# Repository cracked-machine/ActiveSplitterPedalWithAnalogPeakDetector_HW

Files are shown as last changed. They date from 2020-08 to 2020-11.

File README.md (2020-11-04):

## Active 4-way splitter pedal with analog peak detector

Required Kicad Hardware library: https://github.com/cracked-machine/KicadLibrary

- Analog 1->4 splitter circuit with buffered input and output gain controls.
- Analog LED peak detector per output channel.
- Fits in a Hammond 1590BB enclosure (120mm x 95mm).

### System Overview



### Schematic

##### Top Level



##### Power Supply block



##### Buffer/Attenuator block



##### Peak Detector block



## 3D Renderings

__PCB 3D Render (top view)__

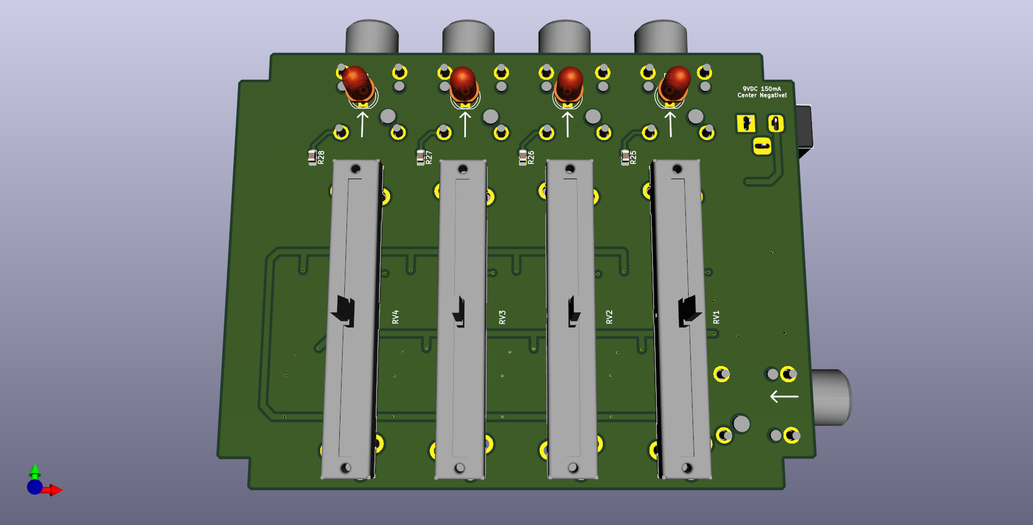
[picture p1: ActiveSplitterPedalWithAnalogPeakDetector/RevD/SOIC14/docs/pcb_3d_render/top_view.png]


__PCB 3D Render (bottom view)__

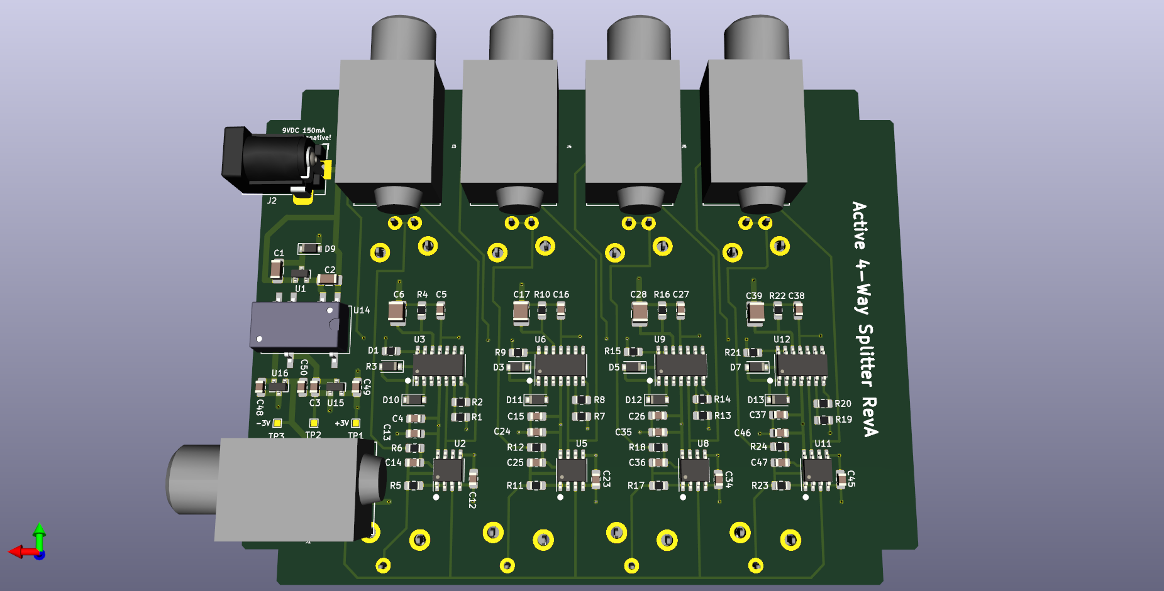
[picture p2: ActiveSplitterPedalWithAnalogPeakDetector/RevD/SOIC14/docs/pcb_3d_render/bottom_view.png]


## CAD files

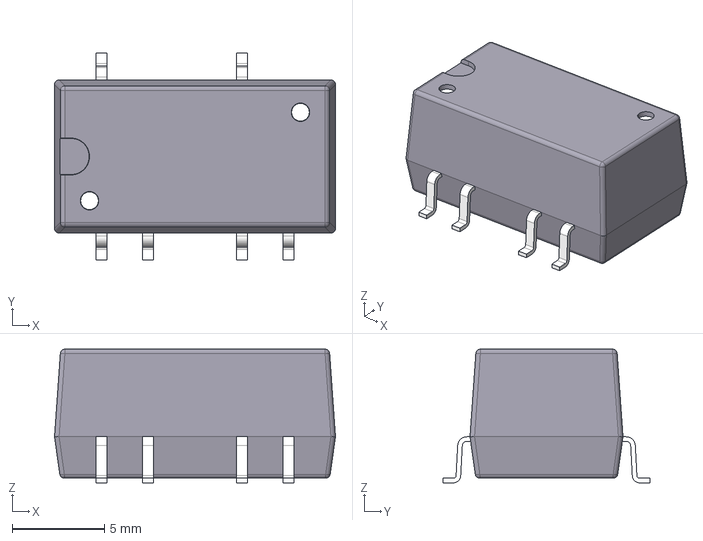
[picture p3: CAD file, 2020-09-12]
ActiveSplitterPedalWithAnalogPeakDetector/RevD/SOIC14/3D/ISA.STEP
15.2 x 11.2 x 7.25 mm

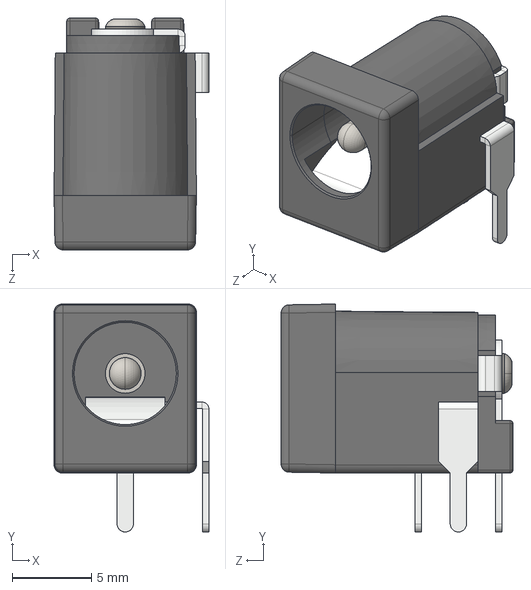
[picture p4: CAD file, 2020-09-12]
ActiveSplitterPedalWithAnalogPeakDetector/RevD/SOIC14/3D/DC Power Jack 5.5mm x 2.1mm.STEP
9.77 x 14.4 x 14.6 mm

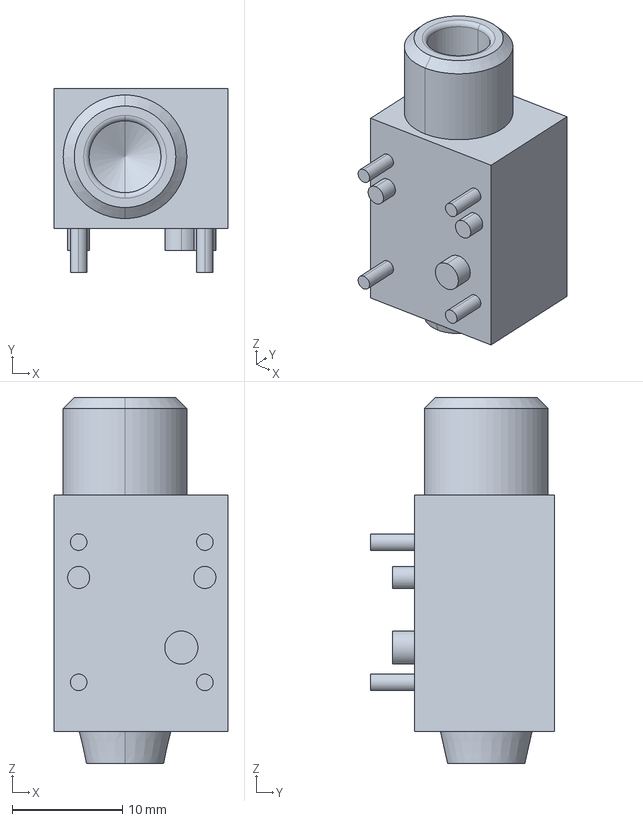
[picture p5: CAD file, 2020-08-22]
ActiveSplitterPedalWithAnalogPeakDetector/RevD/SOIC14/3D/3D+File+NRJ4HF.stp
15.8 x 16.7 x 33.1 mm

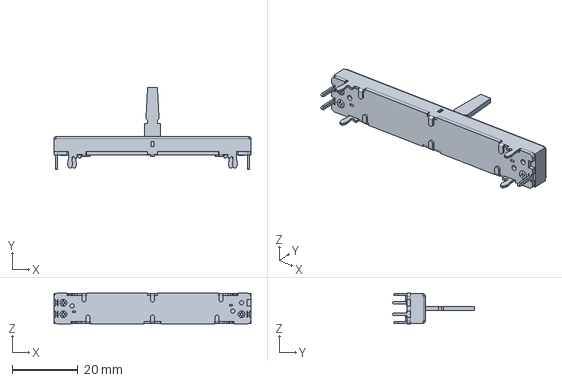
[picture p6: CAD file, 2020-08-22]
ActiveSplitterPedalWithAnalogPeakDetector/RevD/SOIC14/3D/pta4543-2015dpb103.stp
60.0 x 25.0 x 9.30 mm

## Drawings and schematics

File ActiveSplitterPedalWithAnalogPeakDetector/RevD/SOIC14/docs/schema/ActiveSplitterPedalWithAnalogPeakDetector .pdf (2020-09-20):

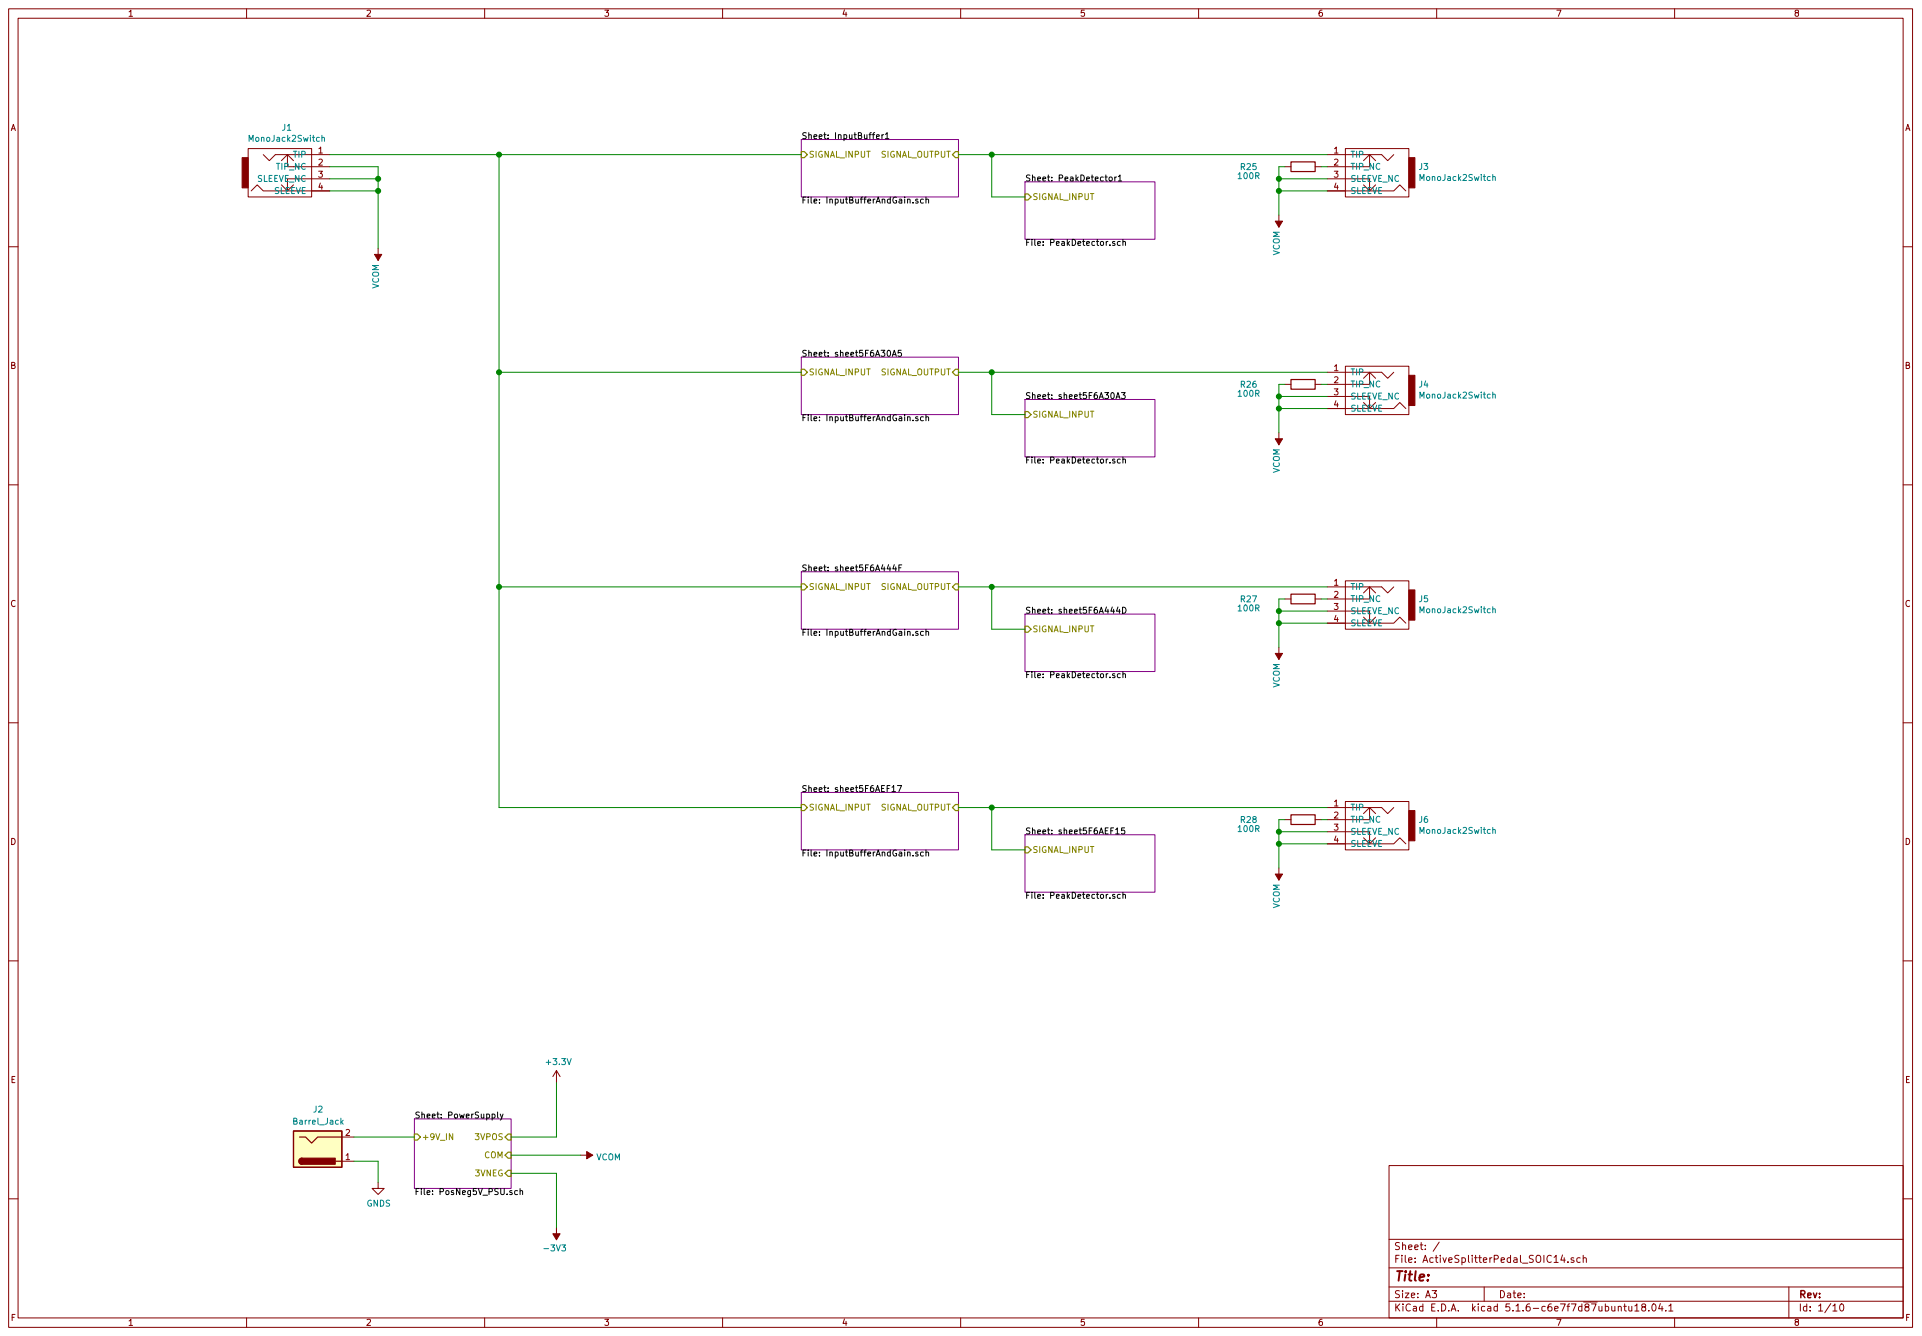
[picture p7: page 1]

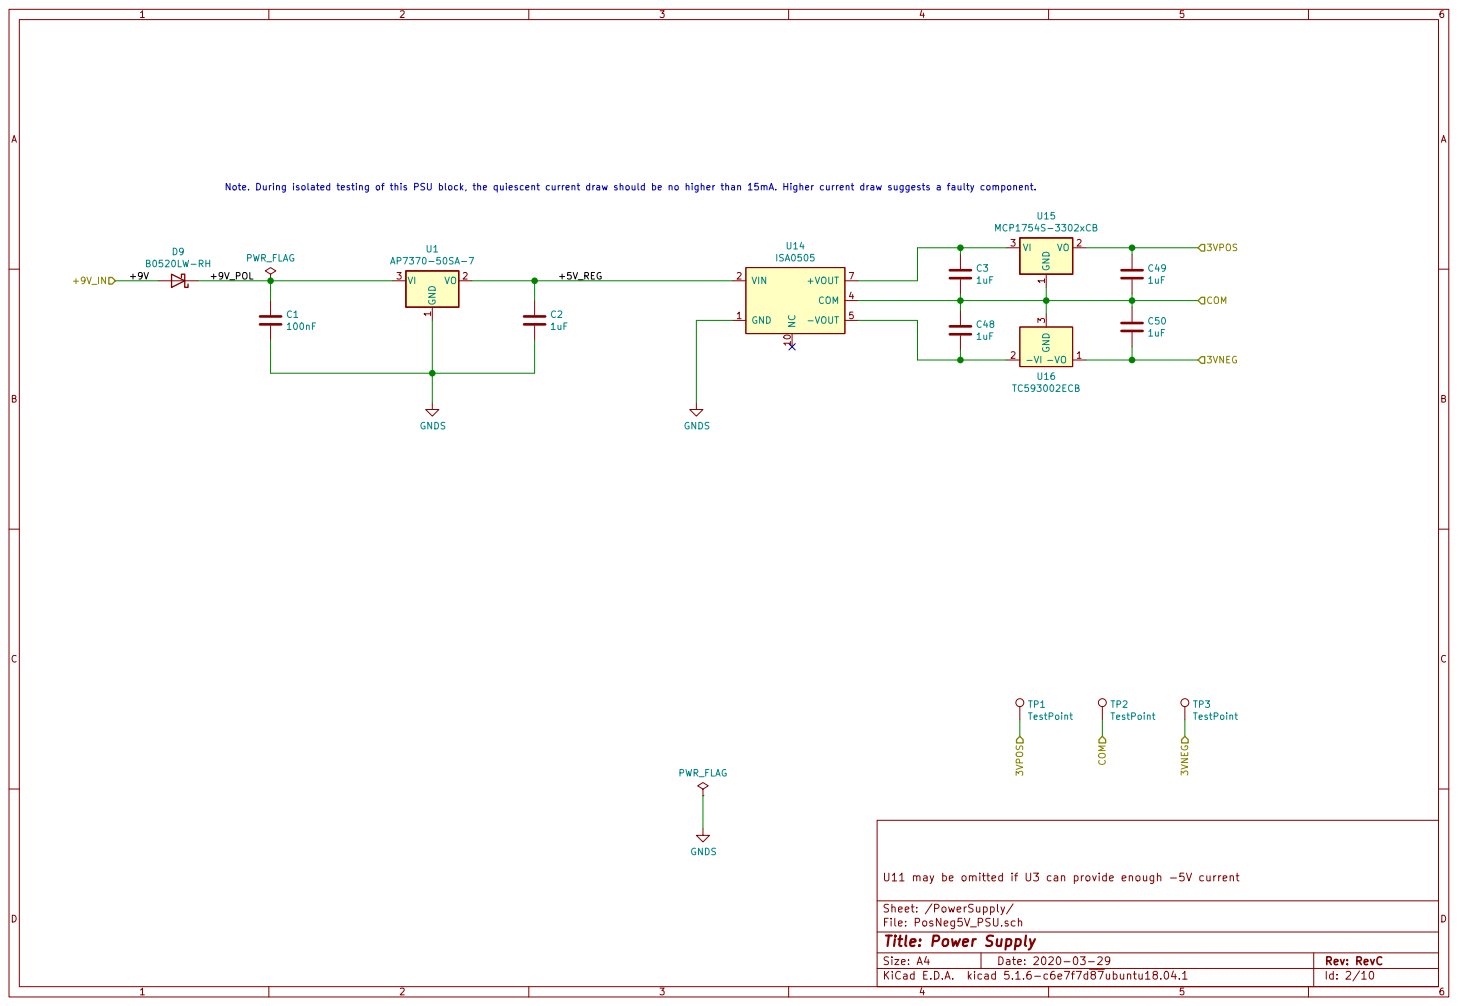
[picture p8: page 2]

U11 may be omitted if U3 can provide enough -5V current GND
ISA0505 GNDS

Note. During isolated testing of this PSU block, the quiescent current draw should be no higher than 15mA. Higher current draw suggests a faulty component.

3 U16 TC593002ECB GNDS GND 1 NC 10 VIN 2 COM 4

Sheet: /PowerSupply/
File: PosNeg5V_PSU.sch
Id: 2/10 Title: Power Supply

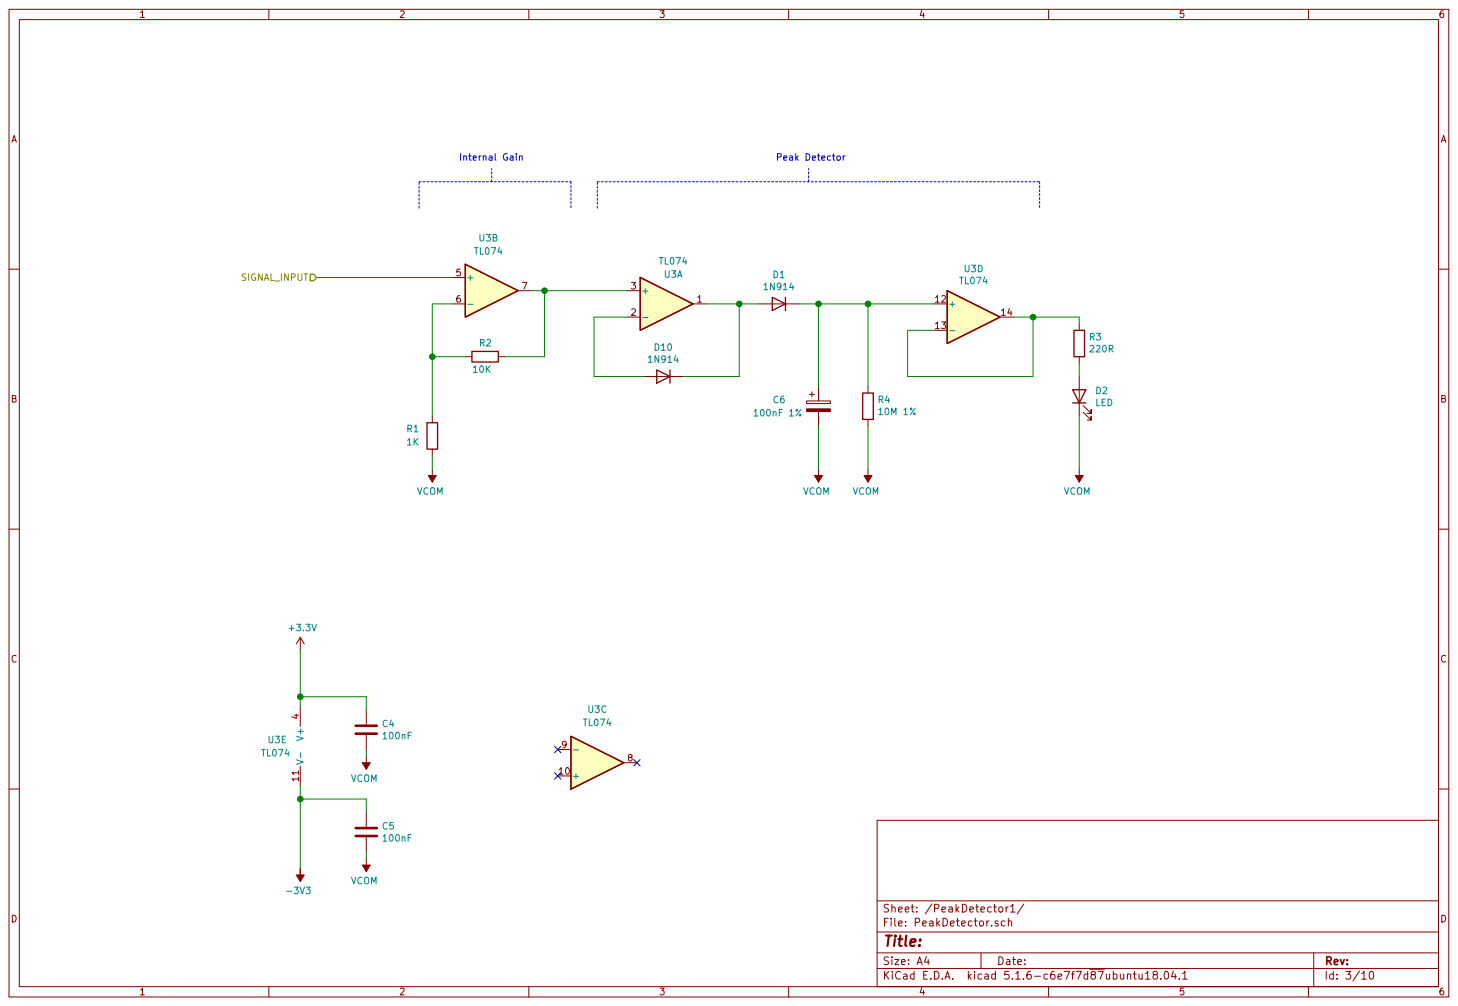
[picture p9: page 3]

Id: 3/10 Title: File: PeakDetector.sch Sheet: /PeakDetector1/ VCOM

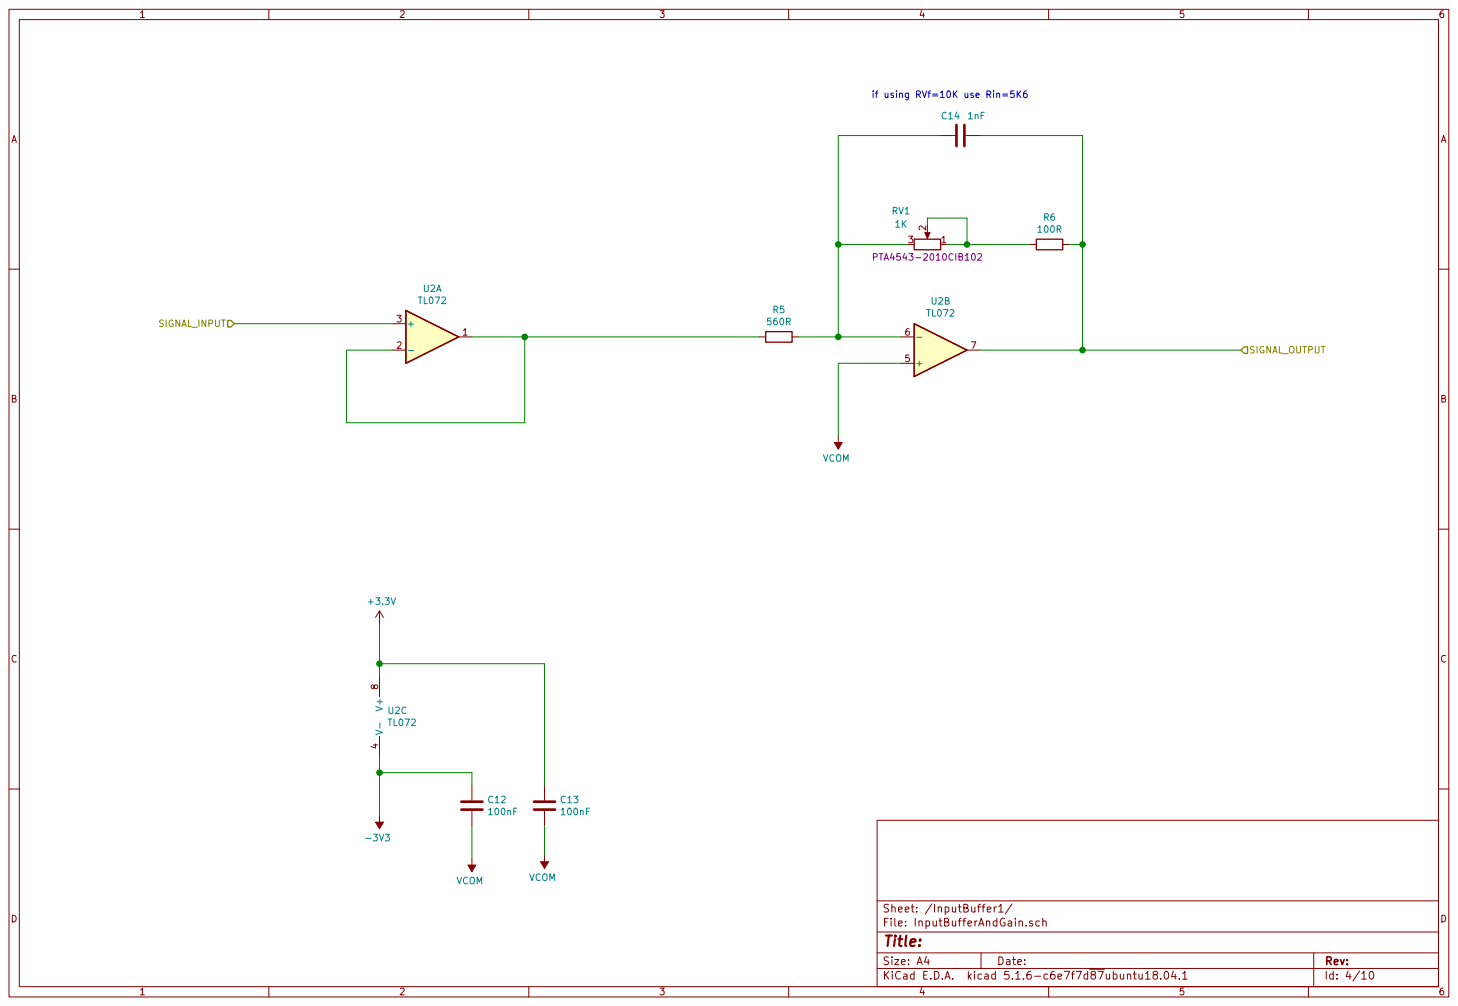
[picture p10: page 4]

if using RVf=10K use Rin=5K6

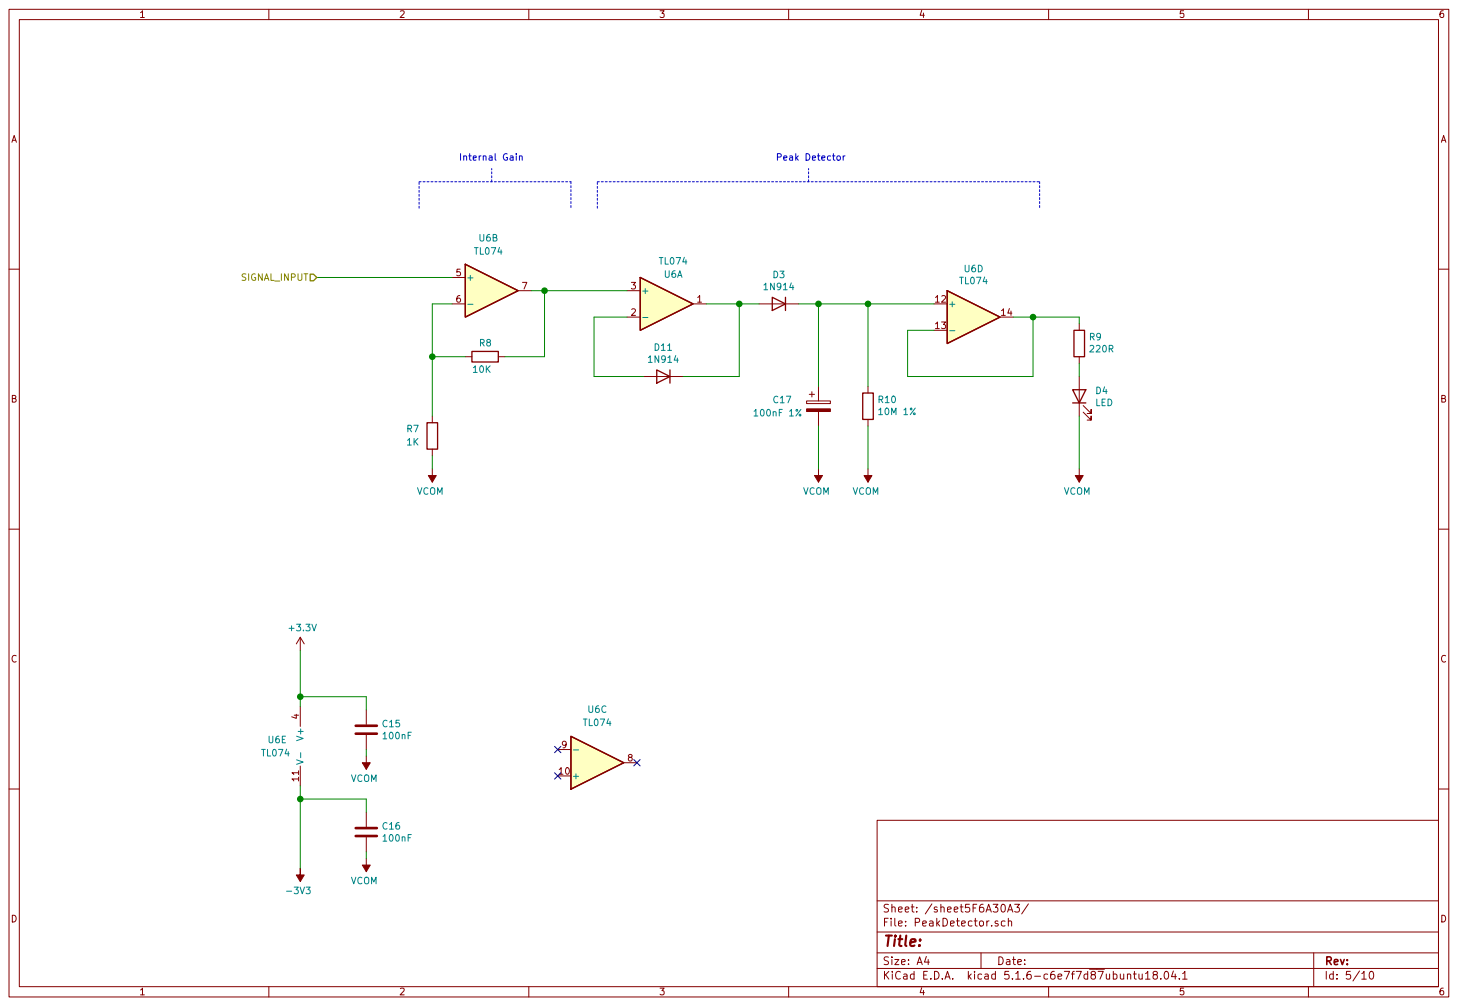
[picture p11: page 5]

Id: 5/10 Title: File: PeakDetector.sch Sheet: /sheet5F6A30A3/ VCOM

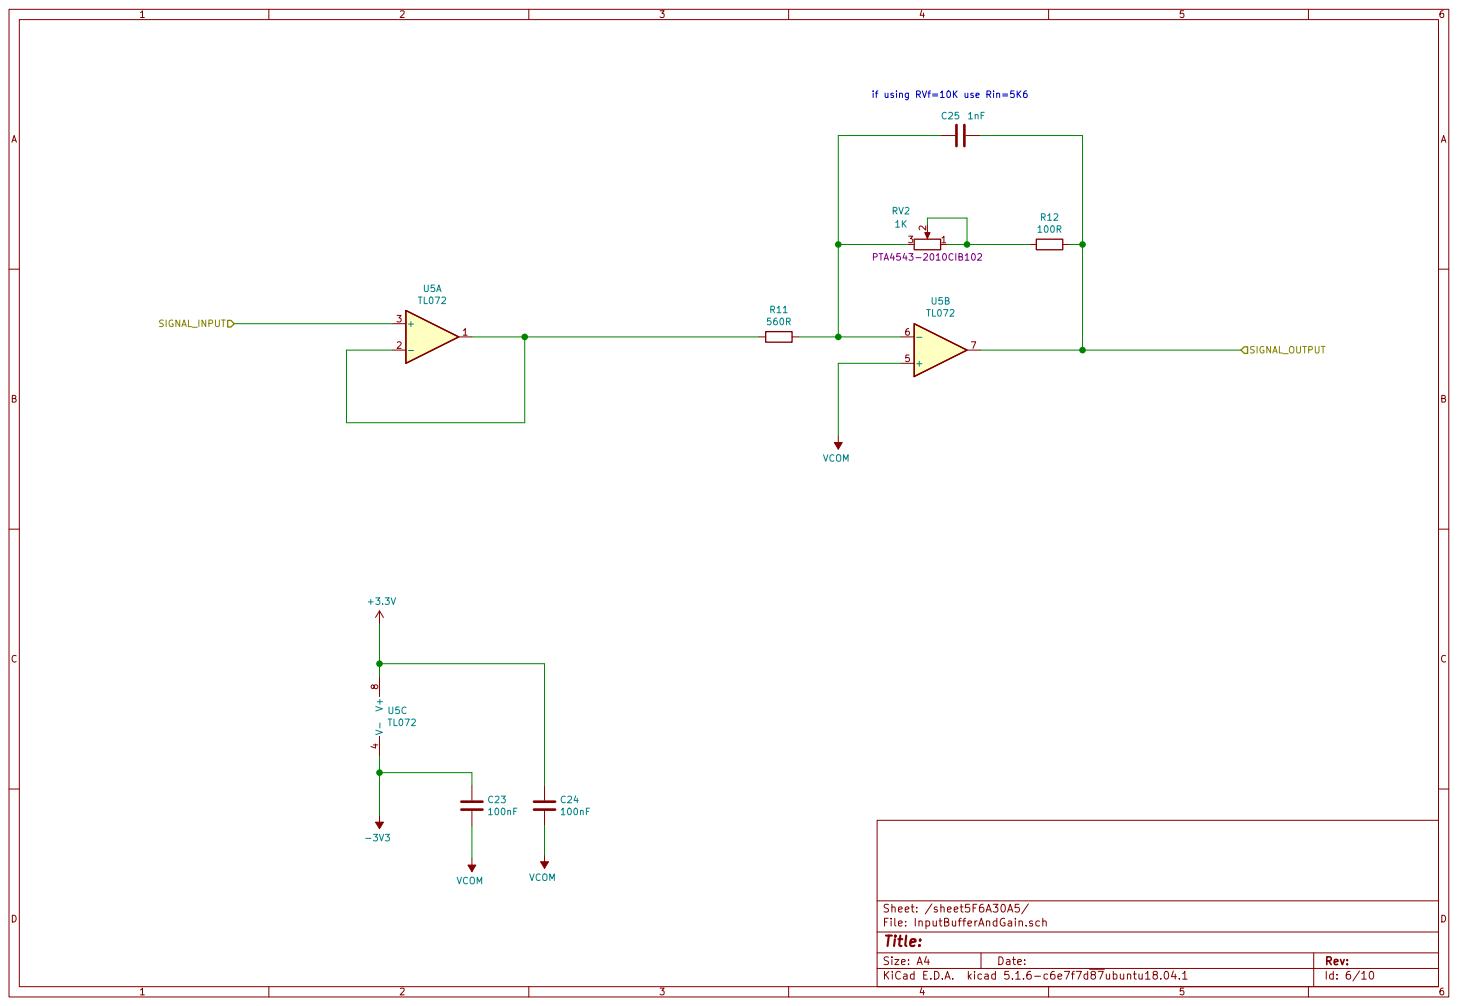
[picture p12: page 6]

if using RVf=10K use Rin=5K6

File: InputBufferAndGain.sch Sheet: /sheet5F6A30A5/
Id: 6/10 Title:

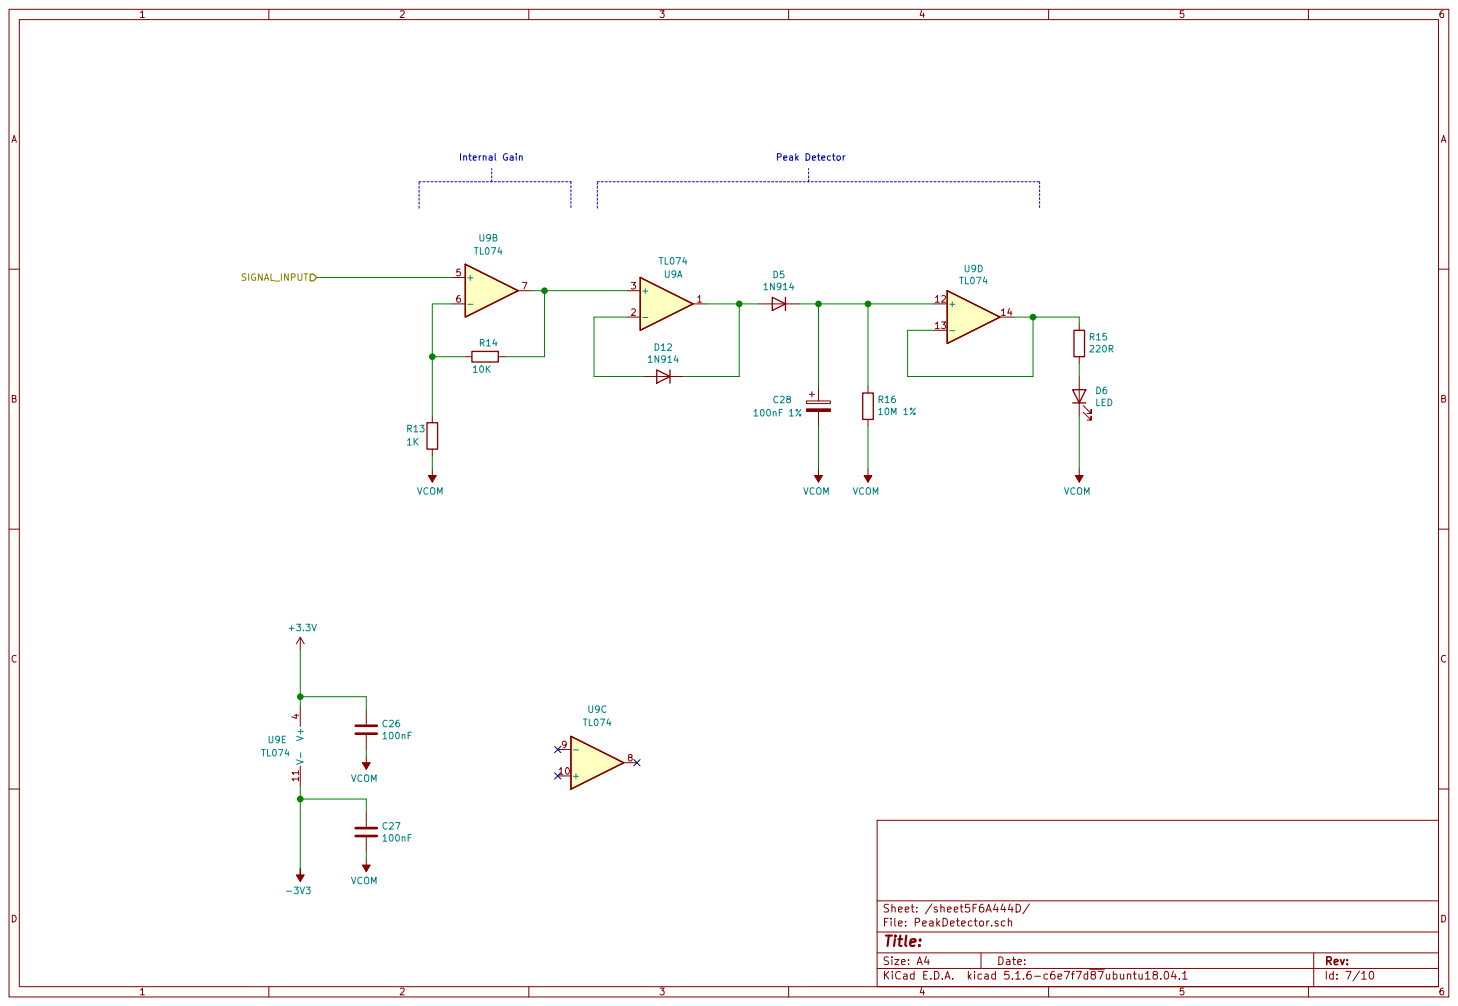
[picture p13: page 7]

Id: 7/10 Title: File: PeakDetector.sch Sheet: /sheet5F6A444D/ VCOM

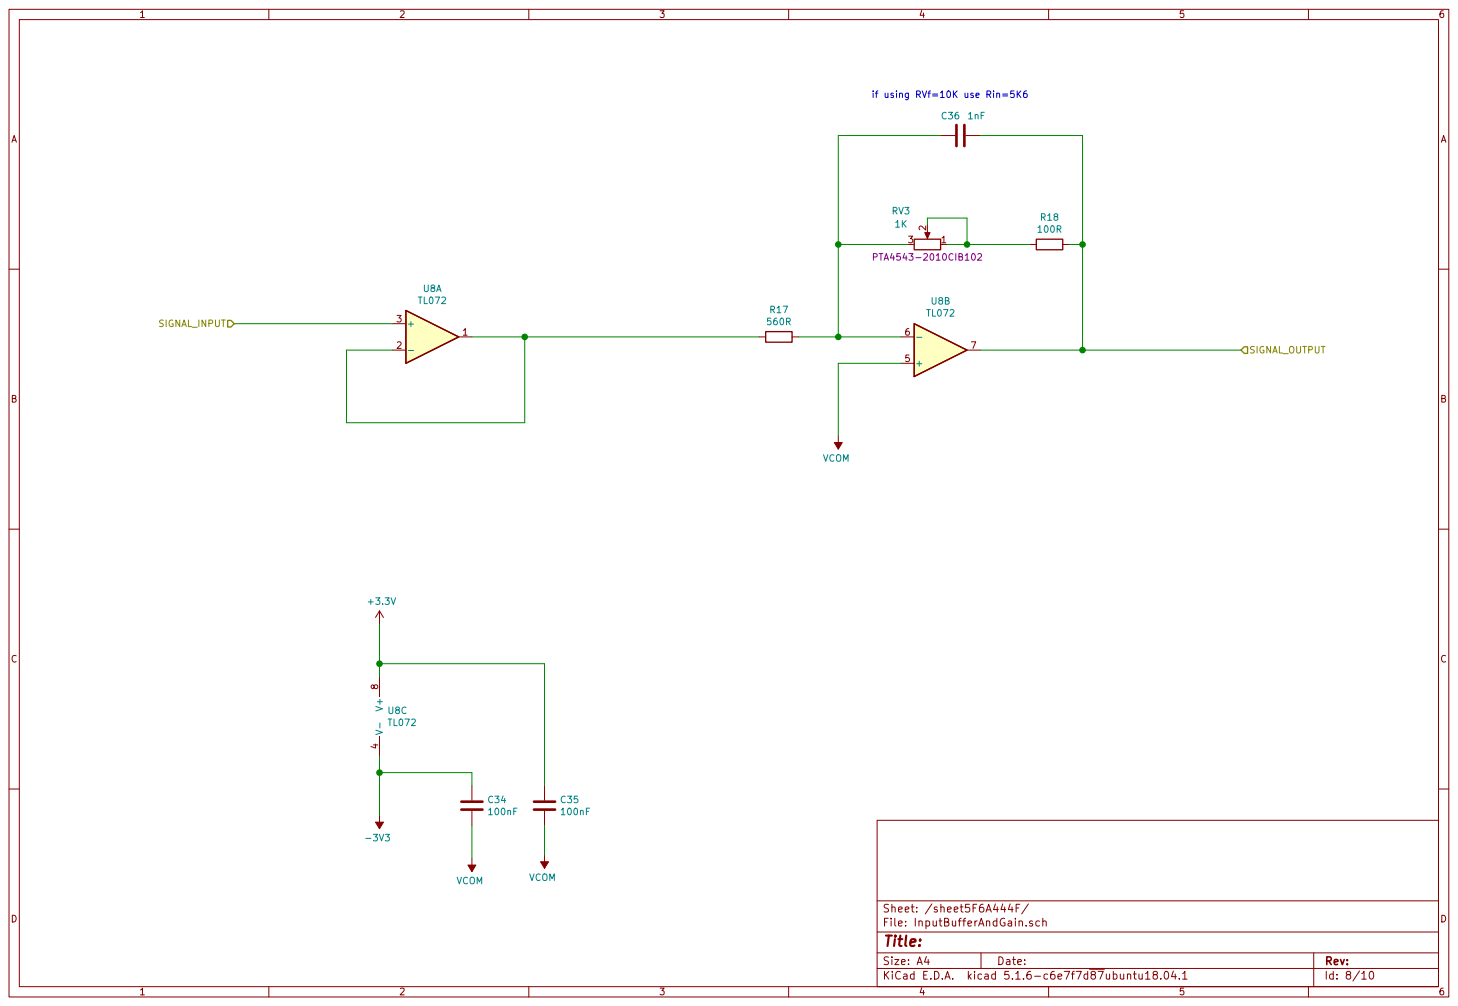
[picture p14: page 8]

if using RVf=10K use Rin=5K6

File: InputBufferAndGain.sch Sheet: /sheet5F6A444F/
Id: 8/10 Title:

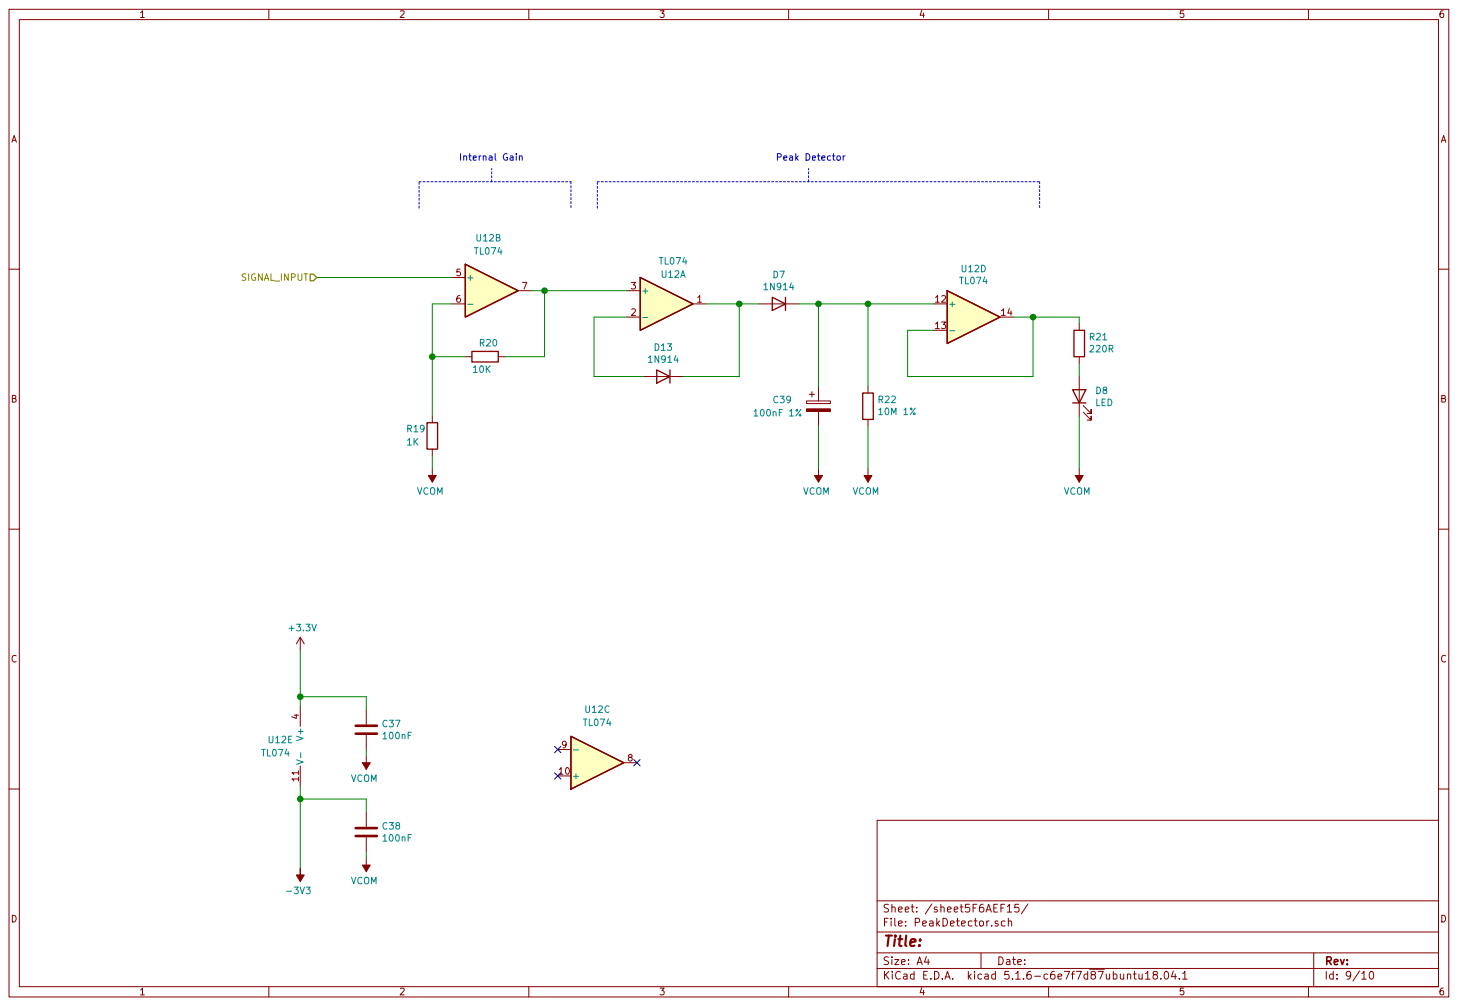
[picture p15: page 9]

Id: 9/10 Title: File: PeakDetector.sch Sheet: /sheet5F6AEF15/ VCOM

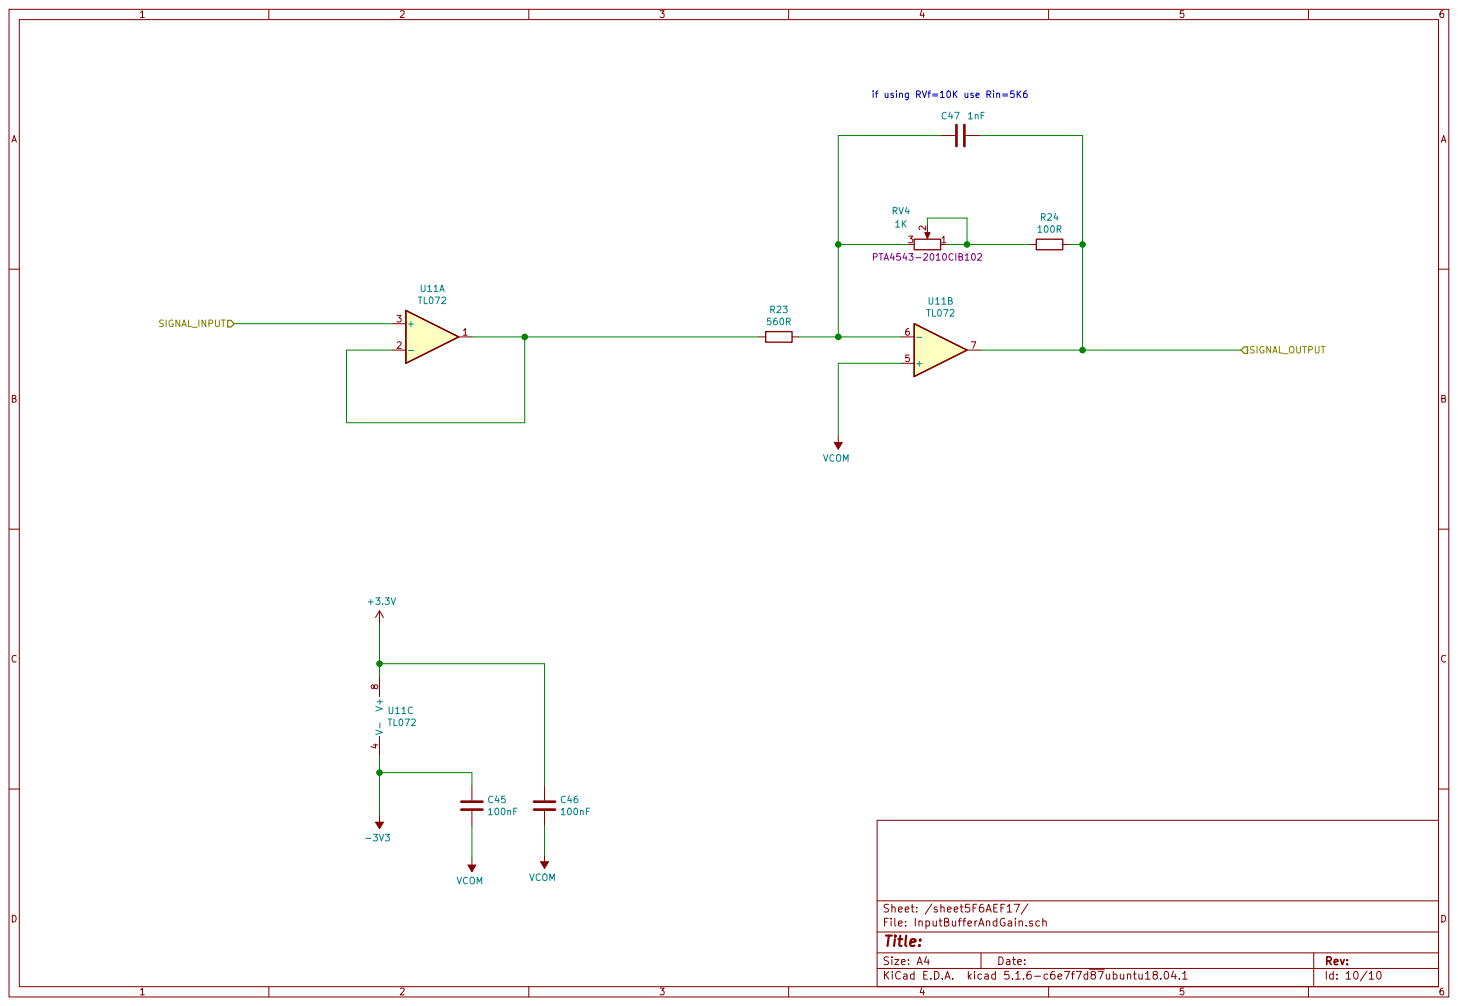
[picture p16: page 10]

if using RVf=10K use Rin=5K6

File: InputBufferAndGain.sch Sheet: /sheet5F6AEF17/
Id: 10/10 Title:

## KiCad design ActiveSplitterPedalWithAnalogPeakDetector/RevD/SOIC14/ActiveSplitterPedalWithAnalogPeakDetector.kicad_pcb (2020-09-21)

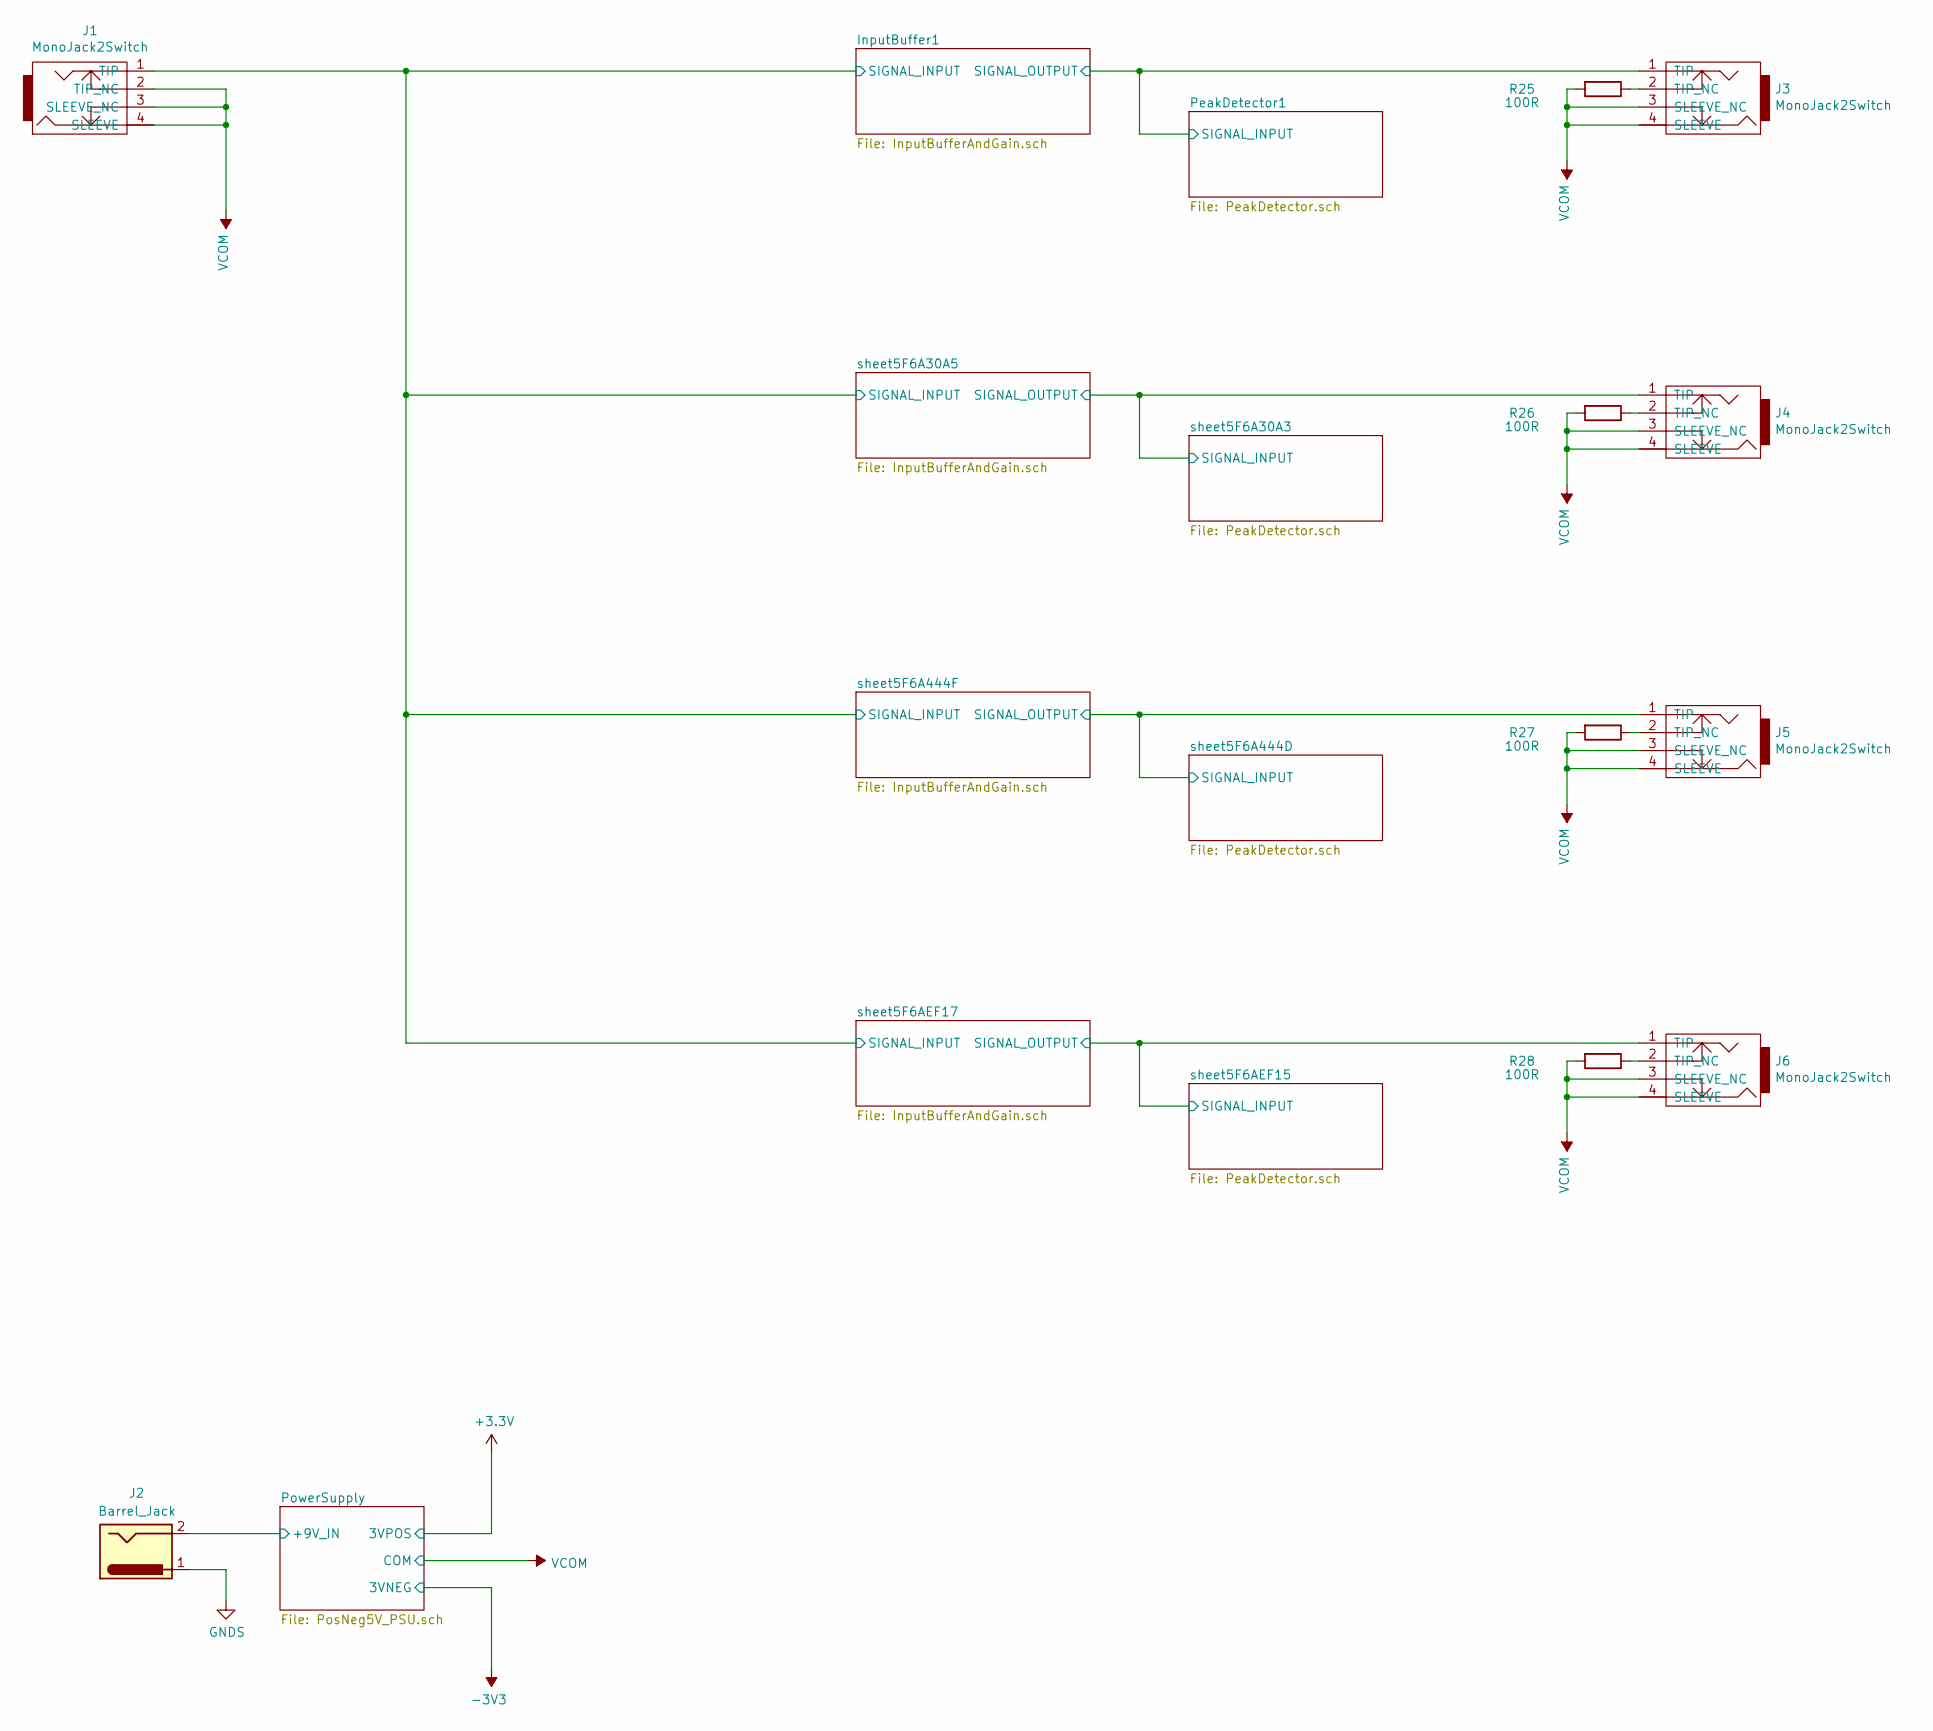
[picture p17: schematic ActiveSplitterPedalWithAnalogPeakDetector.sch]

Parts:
J1, J3, J4, J5, J6: MonoJack2Switch; NRJxHx
J2: Barrel_Jack; BarrelJack_Horizontal
R25, R26, R27, R28: 100R; C_0805_2012Metric_Pad1.15x1.40mm_HandSolder

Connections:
/InputBuffer1/SIGNAL_INPUT: J1.1 (TIP); also elsewhere on the board
/PeakDetector1/SIGNAL_INPUT: J3.1 (TIP); also elsewhere on the board
/PowerSupply/+9V_IN: J2.2; also elsewhere on the board
/sheet5F6A30A3/SIGNAL_INPUT: J4.1 (TIP); also elsewhere on the board
/sheet5F6A444D/SIGNAL_INPUT: J5.1 (TIP); also elsewhere on the board
/sheet5F6AEF15/SIGNAL_INPUT: J6.1 (TIP); also elsewhere on the board
GNDS: J2.1; also elsewhere on the board
unnamed: J3.2 (TIP_NC), R25.1
unnamed: J4.2 (TIP_NC), R26.1
unnamed: J5.2 (TIP_NC), R27.1
unnamed: J6.2 (TIP_NC), R28.1
VCOM: J1.2 (TIP_NC), J1.3 (SLEEVE_NC), J1.4 (SLEEVE), J3.3 (SLEEVE_NC), J3.4 (SLEEVE), J4.3 (SLEEVE_NC), J4.4 (SLEEVE), J5.3 (SLEEVE_NC), J5.4 (SLEEVE), J6.3 (SLEEVE_NC), J6.4 (SLEEVE), R25.2, R26.2, R27.2, R28.2; also elsewhere on the board

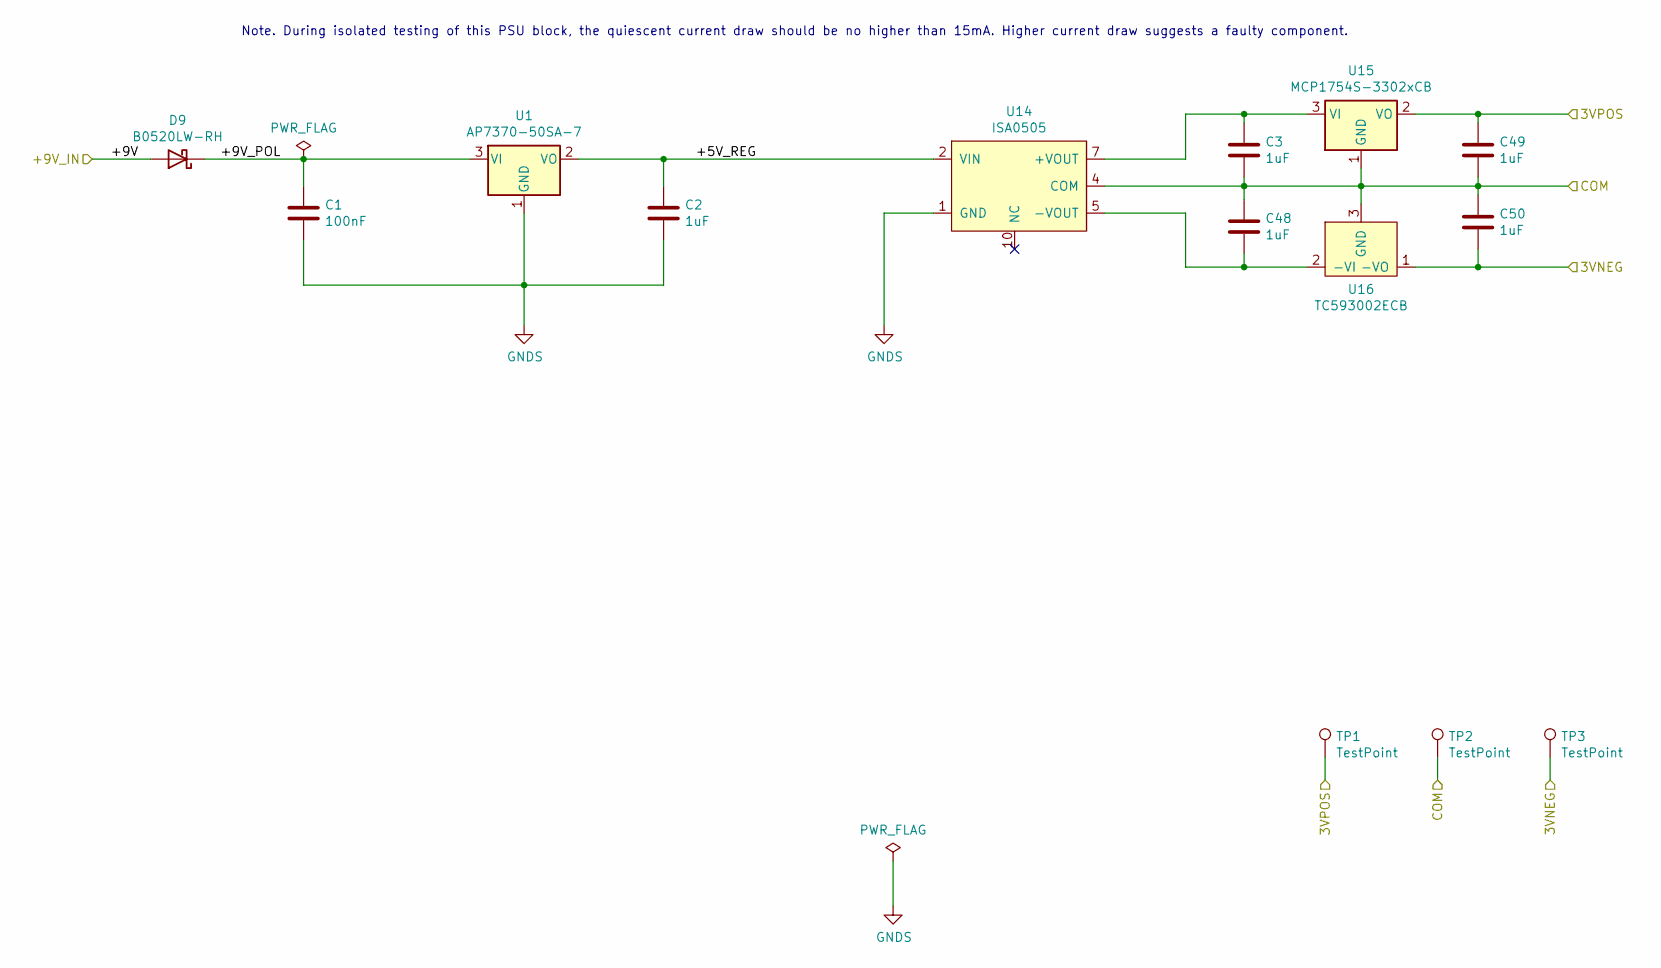
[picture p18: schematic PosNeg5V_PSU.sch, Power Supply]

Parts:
C1: 100nF; C_1206_3216Metric_Pad1.42x1.75mm_HandSolder
C2: 1uF; C_1206_3216Metric_Pad1.42x1.75mm_HandSolder
C3, C48, C49, C50: 1uF; C_0805_2012Metric_Pad1.15x1.40mm_HandSolder
D9: B0520LW-RH; D_SOD-123F
TP1, TP2, TP3: TestPoint; TestPoint_Pad_1.0x1.0mm
U1: AP7370-50SA-7; SOT-23
U14: ISA0505
U15: MCP1754S-3302xCB; SOT-23
U16: TC593002ECB; SOT-23

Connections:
+3V3: C49.1, TP1.1, U15.2 (VO); also elsewhere on the board
-3V3: C50.2, TP3.1, U16.1 (-VO); also elsewhere on the board
/PowerSupply/+5V_REG: C2.1, U1.2 (VO), U14.2 (VIN)
/PowerSupply/+9V_IN: D9.2 (A); also elsewhere on the board
/PowerSupply/+9V_POL: C1.1, D9.1 (K), U1.3 (VI)
GNDS: C1.2, C2.2, U1.1 (GND), U14.1 (GND); also elsewhere on the board
unnamed: C3.1, U14.7 (+VOUT), U15.3 (VI)
unnamed: C48.2, U14.5 (-VOUT), U16.2 (-VI)
VCOM: C3.2, C48.1, C49.2, C50.1, TP2.1, U14.4 (COM), U15.1 (GND), U16.3 (GND); also elsewhere on the board

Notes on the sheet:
Note. During isolated testing of this PSU block, the quiescent current draw should be no higher than 15mA. Higher current draw suggests a faulty component.

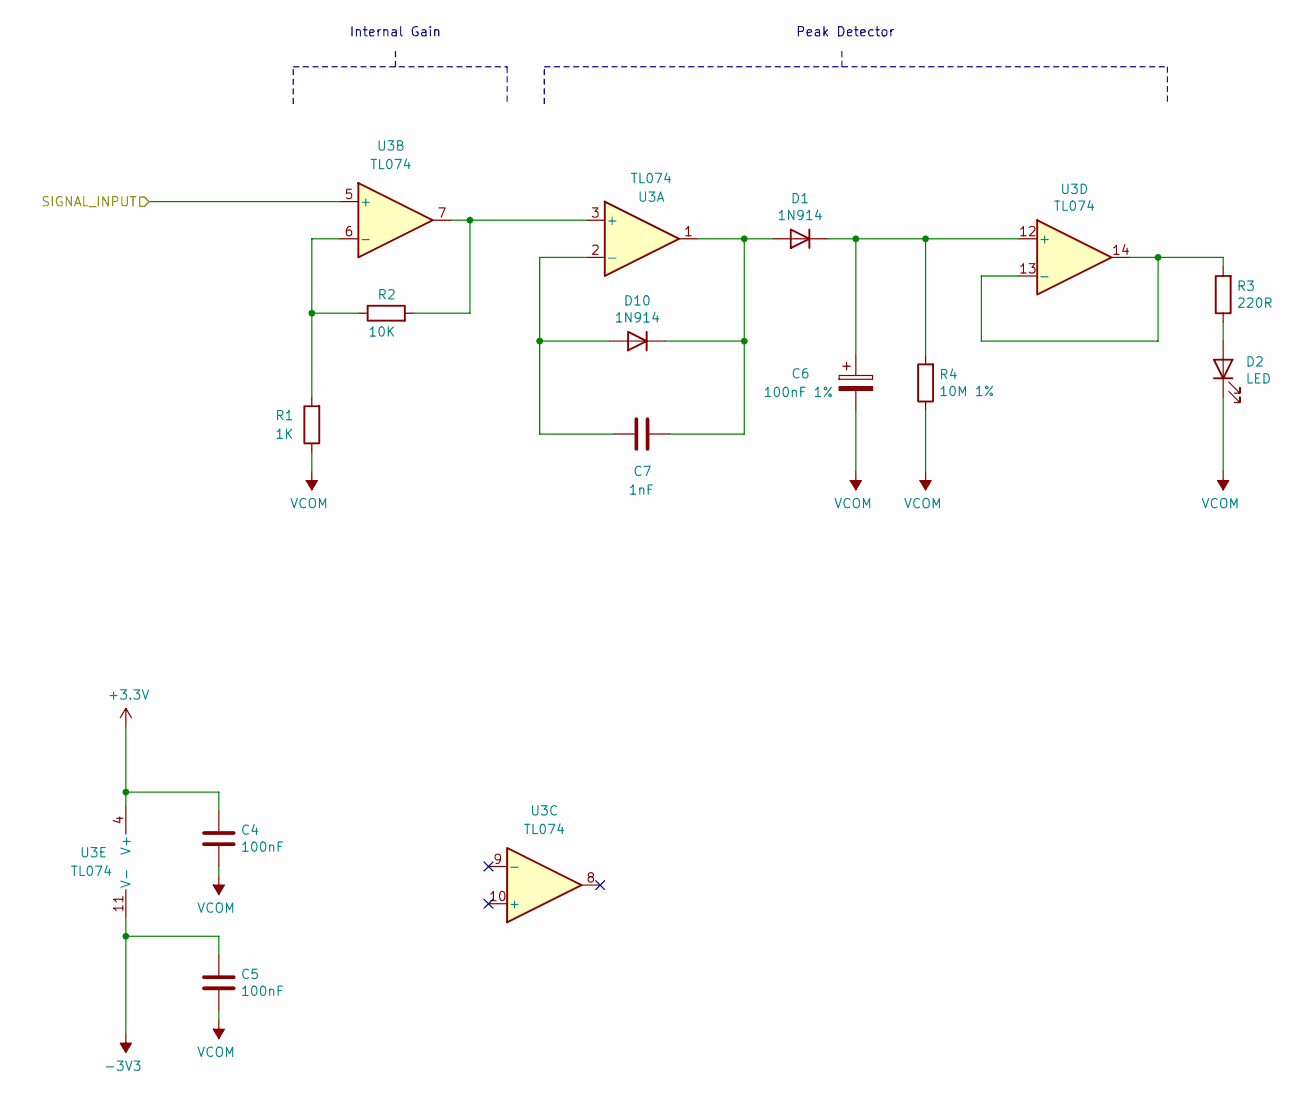
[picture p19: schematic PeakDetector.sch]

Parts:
C4, C5: 100nF; C_0805_2012Metric_Pad1.15x1.40mm_HandSolder
C6: 100nF 1%; C_1210_3225Metric_Pad1.42x2.65mm_HandSolder
C7: 1nF; C_0805_2012Metric_Pad1.15x1.40mm_HandSolder
D1, D10: 1N914; D_SOD-123F
D2: LED; LED_D5.0mm
R1: 1K; R_0805_2012Metric_Pad1.15x1.40mm_HandSolder
R2: 10K; R_0805_2012Metric_Pad1.15x1.40mm_HandSolder
R3: 220R; R_0805_2012Metric_Pad1.15x1.40mm_HandSolder
R4: 10M 1%; R_0805_2012Metric_Pad1.15x1.40mm_HandSolder
U3: TL074; SOIC-14_3.9x8.7mm_P1.27mm

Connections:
+3V3: C4.1, U3.4 (V+); also elsewhere on the board
-3V3: C5.1, U3.11 (V-); also elsewhere on the board
/PeakDetector1/SIGNAL_INPUT: U3.5 (+); also elsewhere on the board
unnamed: C6.1, D1.1 (K), R4.2, U3.12 (+)
unnamed: C7.1, D1.2 (A), D10.1 (K), U3.1
unnamed: C7.2, D10.2 (A), U3.2 (-)
unnamed: D2.2 (A), R3.1
unnamed: R1.2, R2.1, U3.6 (-)
unnamed: R2.2, U3.3 (+), U3.7
unnamed: R3.2, U3.13 (-), U3.14
VCOM: C4.2, C5.2, C6.2, D2.1 (K), R1.1, R4.1; also elsewhere on the board

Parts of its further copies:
C8, C9, C10: 1nF; C_0805_2012Metric_Pad1.15x1.40mm_HandSolder
C15, C16, C26, C27, C37, C38: 100nF; C_0805_2012Metric_Pad1.15x1.40mm_HandSolder
C17, C28, C39: 100nF 1%; C_1210_3225Metric_Pad1.42x2.65mm_HandSolder
D3, D5, D7, D11, D12, D13: 1N914; D_SOD-123F
D4, D6, D8: LED; LED_D5.0mm
R7, R13, R19: 1K; R_0805_2012Metric_Pad1.15x1.40mm_HandSolder
R8, R14, R20: 10K; R_0805_2012Metric_Pad1.15x1.40mm_HandSolder
R9, R15, R21: 220R; R_0805_2012Metric_Pad1.15x1.40mm_HandSolder
R10, R16, R22: 10M 1%; R_0805_2012Metric_Pad1.15x1.40mm_HandSolder
U6, U9, U12: TL074; SOIC-14_3.9x8.7mm_P1.27mm

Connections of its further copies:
+3V3: C15.1, C26.1, C37.1, U6.4 (V+), U9.4 (V+), U12.4 (V+); also elsewhere on the board
-3V3: C16.1, C27.1, C38.1, U6.11 (V-), U9.11 (V-), U12.11 (V-); also elsewhere on the board
/sheet5F6A30A3/SIGNAL_INPUT: U6.5 (+); also elsewhere on the board
/sheet5F6A444D/SIGNAL_INPUT: U9.5 (+); also elsewhere on the board
/sheet5F6AEF15/SIGNAL_INPUT: U12.5 (+); also elsewhere on the board
unnamed: C8.1, D3.2 (A), D11.1 (K), U6.1
unnamed: C8.2, D11.2 (A), U6.2 (-)
unnamed: C9.1, D5.2 (A), D12.1 (K), U9.1
unnamed: C9.2, D12.2 (A), U9.2 (-)
unnamed: C10.1, D7.2 (A), D13.1 (K), U12.1
unnamed: C10.2, D13.2 (A), U12.2 (-)
unnamed: C17.1, D3.1 (K), R10.2, U6.12 (+)
unnamed: C28.1, D5.1 (K), R16.2, U9.12 (+)
unnamed: C39.1, D7.1 (K), R22.2, U12.12 (+)
unnamed: D4.2 (A), R9.1
unnamed: D6.2 (A), R15.1
unnamed: D8.2 (A), R21.1
unnamed: R7.2, R8.1, U6.6 (-)
unnamed: R8.2, U6.3 (+), U6.7
unnamed: R9.2, U6.13 (-), U6.14
unnamed: R13.2, R14.1, U9.6 (-)
unnamed: R14.2, U9.3 (+), U9.7
unnamed: R15.2, U9.13 (-), U9.14
unnamed: R19.2, R20.1, U12.6 (-)
unnamed: R20.2, U12.3 (+), U12.7
unnamed: R21.2, U12.13 (-), U12.14
VCOM: C15.2, C16.2, C17.2, C26.2, C27.2, C28.2, C37.2, C38.2, C39.2, D4.1 (K), D6.1 (K), D8.1 (K), R7.1, R10.1, R13.1, R16.1, R19.1, R22.1; also elsewhere on the board

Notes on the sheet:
Internal Gain
Peak Detector

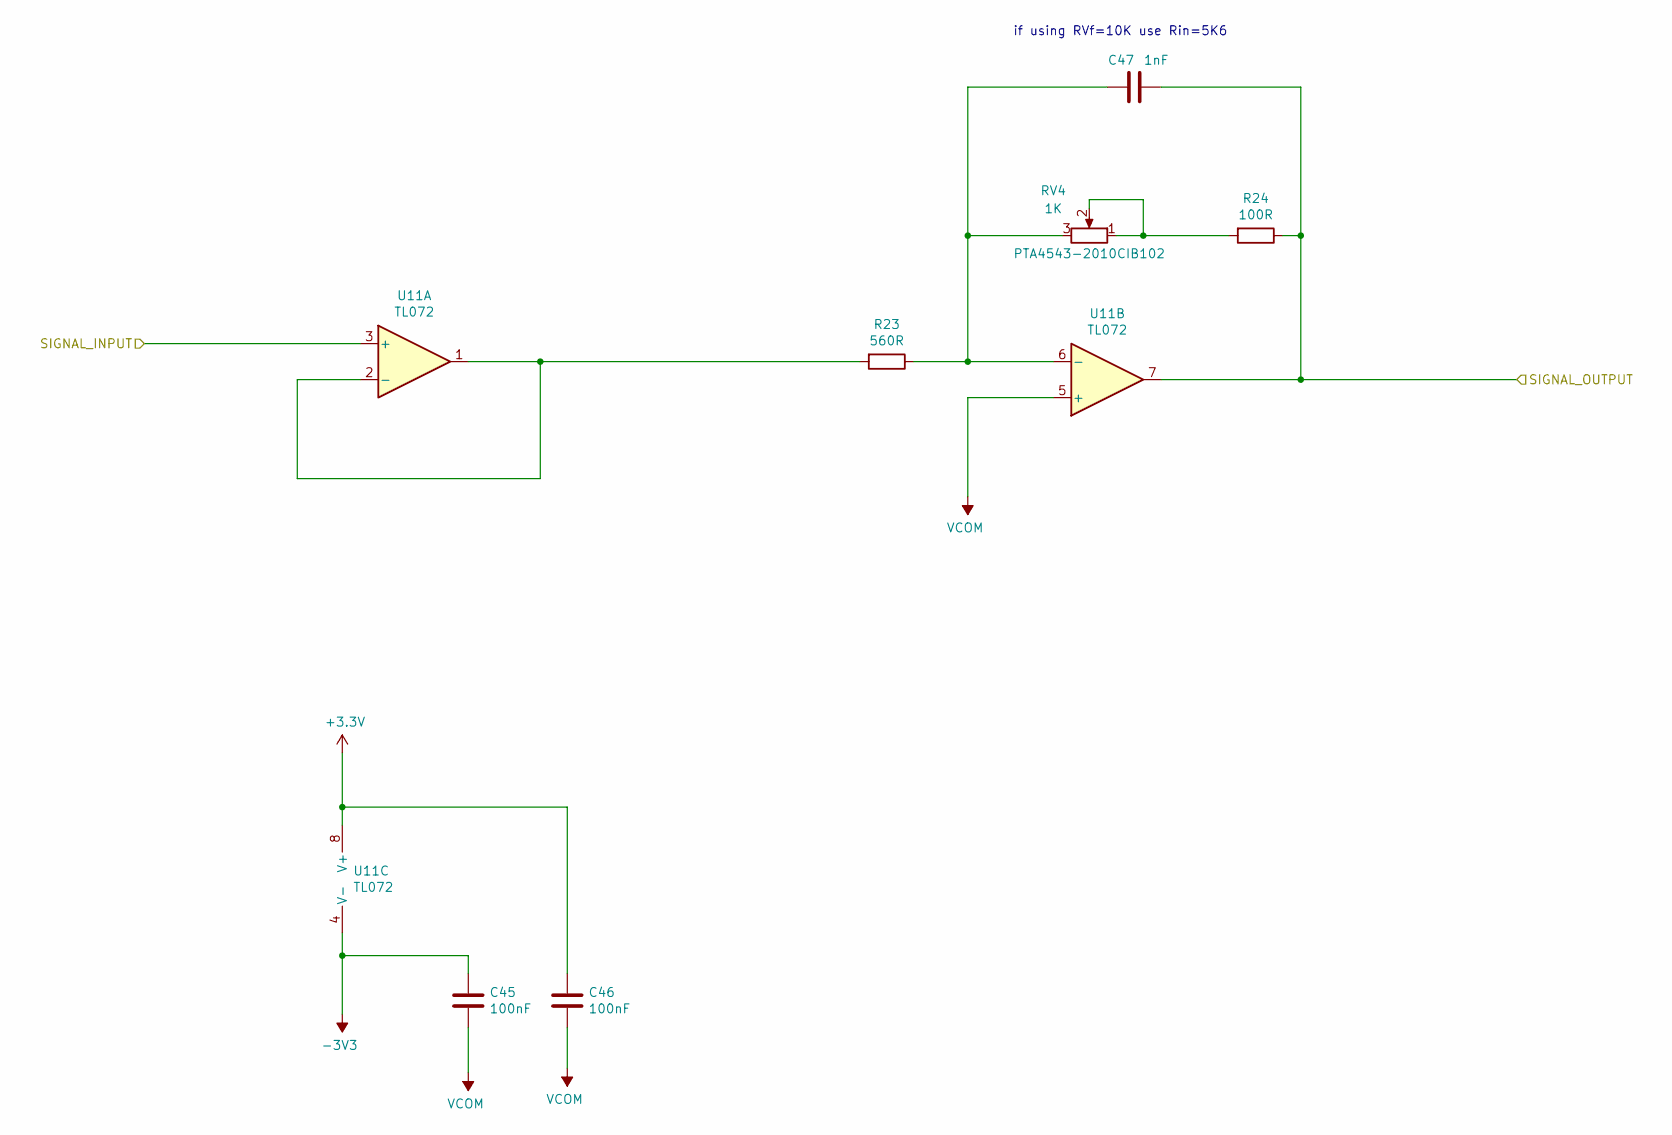
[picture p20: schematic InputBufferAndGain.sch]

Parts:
C12, C13: 100nF; C_0805_2012Metric_Pad1.15x1.40mm_HandSolder
C14: 1nF; C_0805_2012Metric_Pad1.15x1.40mm_HandSolder
R5: 560R; R_0805_2012Metric_Pad1.15x1.40mm_HandSolder
R6: 100R; R_0805_2012Metric_Pad1.15x1.40mm_HandSolder
RV1: 1K; Slider_PTA4543_60MM; Part No. PTA4543-2010CIB102
U2: TL072; SOIC-8_3.9x4.9mm_P1.27mm

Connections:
+3V3: C13.1, U2.8 (V+); also elsewhere on the board
-3V3: C12.1, U2.4 (V-); also elsewhere on the board
/InputBuffer1/SIGNAL_INPUT: U2.3 (+); also elsewhere on the board
/PeakDetector1/SIGNAL_INPUT: C14.1, R6.1, U2.7; also elsewhere on the board
unnamed: C14.2, R5.1, RV1.3, U2.6 (-)
unnamed: R5.2, U2.1, U2.2 (-)
unnamed: R6.2, RV1.1, RV1.2
VCOM: C12.2, C13.2, U2.5 (+); also elsewhere on the board

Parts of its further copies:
C23, C24, C34, C35, C45, C46: 100nF; C_0805_2012Metric_Pad1.15x1.40mm_HandSolder
C25, C36, C47: 1nF; C_0805_2012Metric_Pad1.15x1.40mm_HandSolder
R11, R17, R23: 560R; R_0805_2012Metric_Pad1.15x1.40mm_HandSolder
R12, R18, R24: 100R; R_0805_2012Metric_Pad1.15x1.40mm_HandSolder
RV2, RV3, RV4: 1K; Slider_PTA4543_60MM; Part No. PTA4543-2010CIB102
U5, U8, U11: TL072; SOIC-8_3.9x4.9mm_P1.27mm

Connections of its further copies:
+3V3: C24.1, C35.1, C46.1, U5.8 (V+), U8.8 (V+), U11.8 (V+); also elsewhere on the board
-3V3: C23.1, C34.1, C45.1, U5.4 (V-), U8.4 (V-), U11.4 (V-); also elsewhere on the board
/InputBuffer1/SIGNAL_INPUT: U5.3 (+), U8.3 (+), U11.3 (+); also elsewhere on the board
/sheet5F6A30A3/SIGNAL_INPUT: C25.1, R12.1, U5.7; also elsewhere on the board
/sheet5F6A444D/SIGNAL_INPUT: C36.1, R18.1, U8.7; also elsewhere on the board
/sheet5F6AEF15/SIGNAL_INPUT: C47.1, R24.1, U11.7; also elsewhere on the board
unnamed: C25.2, R11.1, RV2.3, U5.6 (-)
unnamed: C36.2, R17.1, RV3.3, U8.6 (-)
unnamed: C47.2, R23.1, RV4.3, U11.6 (-)
unnamed: R11.2, U5.1, U5.2 (-)
unnamed: R12.2, RV2.1, RV2.2
unnamed: R17.2, U8.1, U8.2 (-)
unnamed: R18.2, RV3.1, RV3.2
unnamed: R23.2, U11.1, U11.2 (-)
unnamed: R24.2, RV4.1, RV4.2
VCOM: C23.2, C24.2, C34.2, C35.2, C45.2, C46.2, U5.5 (+), U8.5 (+), U11.5 (+); also elsewhere on the board

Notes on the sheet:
if using RVf=10K use Rin=5K6

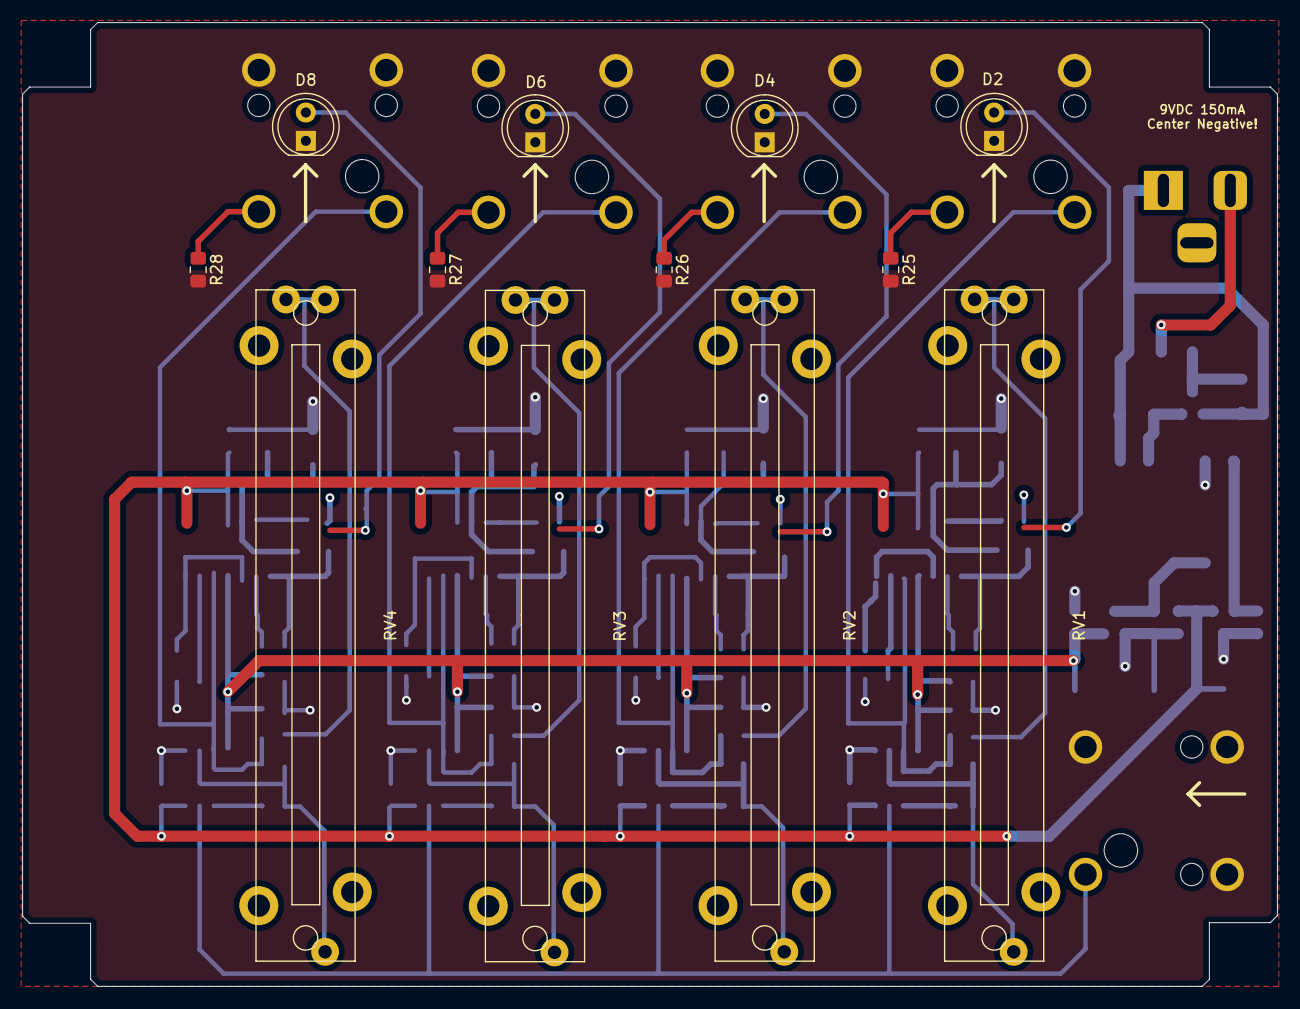
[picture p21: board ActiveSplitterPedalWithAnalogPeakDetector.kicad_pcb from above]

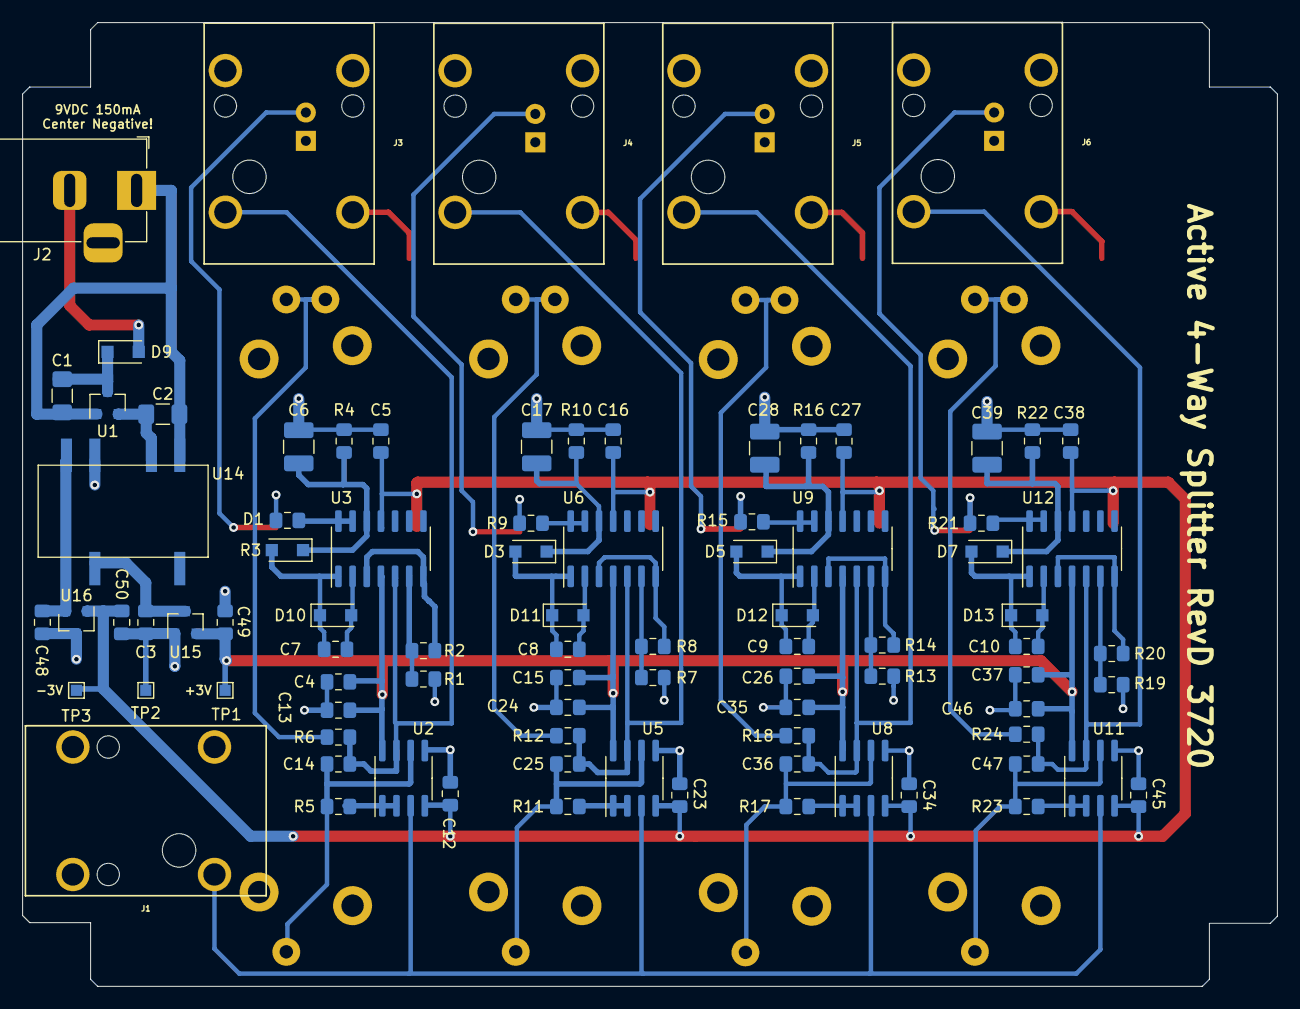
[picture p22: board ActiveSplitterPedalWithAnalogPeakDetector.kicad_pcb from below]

Board: 2 copper layers, 112.5 x 86.4 mm, 100 parts (88 on the bottom side), 58 nets.

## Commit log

2020-08-13 Added Schematic for SOT23 and TSSOP based designs
    [ActiveSplitterPedal_SOT23.kicad_pcb, ActiveSplitterPedal_SOT23.sch, ActiveSplitterPedal_TSSOP.kicad_pcb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]
2020-08-15 updated schematic
    [ActiveSplitterPedal_SOT23.kicad_pcb, ActiveSplitterPedal_SOT23.sch, SignalBuffer.sch]
2020-08-15 SOT23 REVA draft layout completed
    [ActiveSplitterPedal_SOT23.kicad_pcb, ActiveSplitterPedal_SOT23.sch, PosNeg5V_PSU.sch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]
2020-08-16 updated SOT23 design layout outline to use 1590BB
    [ActiveSplitterPedal_SOT23.kicad_pcb]
2020-08-17 upgraded opamp from OPA842 to OPA197 (better performance/lower price)
    [ActiveSplitterPedal_SOT23.sch, SignalBuffer.sch]
2020-08-20 Completed RevA layout
    [2AmpInvertingGainAndPrecisionDetector.sch, 3AmpInvertingGainAndPrecisionDetector.sch, ActiveSplitterPedal_SOT23.kicad_pcb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]
2020-08-20 Renamed kicad project to _SOIC14, removed unused hierarchical sheets
    [2AmpInvertingGainAndPrecisionDetector.sch, 3AmpInvertingGainAndPrecisionDetector.sch, ActiveSplitterPedal_SOIC14.kicad_pcb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]
2020-08-21 RevA HW updates
    - Replaced SW Diode with Schottky Diode
    - Added one charge pump IC per quad opamp (60mA each)
    [ActiveSplitterPedal_SOIC14.kicad_pcb, ActiveSplitterPedal_SOIC14.sch, InvGainAndPeakDetector.sch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]
2020-08-22 Updated RevA layout
    [3D+File+NRJ4HF.stp, ActiveSplitterPedal_SOIC14.kicad_pcb, ActiveSplitterPedal_SOIC14.sch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]
2020-08-23 Adjusted layout edges using Hammond 1590BB outline
    - Moved components to fit within reduced board area
    [ActiveSplitterPedal_SOIC14.kicad_pcb]
2020-08-27 updated RevA layout
    Moved components so that faders would be in centred and symmetrical positions
    [ActiveSplitterPedal_SOIC14.kicad_pcb]
2020-08-31 added uv etch layout
    [ActiveSplitterPedal_SOIC14.kicad_pcb, PosNeg5V_PSU.sch]
2020-09-01 readme update
    - Added system overview
    - Add 3d pcb renders
2020-09-01 update layout + pcb 3d render
    [ActiveSplitterPedal_SOIC14.kicad_pcb]
2020-09-04 updated hw
    - Updated RevA charge pump RC post filter component values for Fc=72KHz
    - Updated RevA for gain opamp components
    - Branched off RevB to improve design to use internal gain for peak detector
    [2AmpInvertingGainAndPrecisionDetector.sch, 3AmpInvertingGainAndPrecisionDetector.sch, 3D+File+NRJ4HF.stp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]
2020-09-05 updated hw
    completed revb layout
    [ActiveSplitterPedal_SOIC14.kicad_pcb, InvGainAndPeakDetector.sch]
2020-09-06 Completed RevC layout
    [2AmpInvertingGainAndPrecisionDetector.sch, 3AmpInvertingGainAndPrecisionDetector.sch, 3D+File+NRJ4HF.stp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]
2020-09-07 Updated HW
    Added RevD layout (single unreg DC-DC module with dual supply LDOs)
    [2AmpInvertingGainAndPrecisionDetector.sch, 3AmpInvertingGainAndPrecisionDetector.sch, 3D+File+NRJ4HF.stp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]
2020-09-08 removed unused hierarchical sheets
    [2AmpInvertingGainAndPrecisionDetector.sch, 3AmpInvertingGainAndPrecisionDetector.sch, InputBuffer.sch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]
2020-09-10 updated hw
    - Changed first regulator from SE8250X2 to AP7370
    - Tested PSU block, added notes to schematic. No load test yet.
    [PosNeg5V_PSU.sch]
2020-09-13 fixed peak detector
    [ActiveSplitterPedal_SOIC14.kicad_pcb, InputBufferAndGain.sch, PeakDetector.sch]
2020-09-13 updated layout
    [ActiveSplitterPedal_SOIC14.kicad_pcb, ActiveSplitterPedal_SOIC14.sch, InputBufferAndGain.sch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]
2020-09-13 Completed RevD
    [2AmpInvertingGainAndPrecisionDetector.sch, 3AmpInvertingGainAndPrecisionDetector.sch, 3D+File+NRJ4HF.stp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]
2020-09-20 updated hw
    - Changed peak detector gain feedback resistor to 10K
    - Changed peak detector storage cap to 100nF
    [ActiveSplitterPedal_SOIC14.kicad_pcb, InputBufferAndGain.sch, PeakDetector.sch]
2020-09-21 updated docs
    - added missing refs to gerbers
    - added case template
    [ActiveSplitterPedal_SOIC14-B_Cu.gbr, ActiveSplitterPedal_SOIC14-B_Mask.gbr, ActiveSplitterPedal_SOIC14-B_SilkS.gbr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]
2020-09-21 updated hw
    added feedback cap to peak detector (help prevent oscillation)
    [ActiveSplitterPedal_SOIC14-B_Cu.gbr, ActiveSplitterPedal_SOIC14-B_Mask.gbr, ActiveSplitterPedal_SOIC14-B_SilkS.gbr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]
2020-09-26 updated name and paths, updated readme
    [3D+File+NRJ4HF.stp, ActiveSplitterPedalWithAnalogPeakDetector.kicad_pcb, ActiveSplitterPedalWithAnalogPeakDetector.sch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]
